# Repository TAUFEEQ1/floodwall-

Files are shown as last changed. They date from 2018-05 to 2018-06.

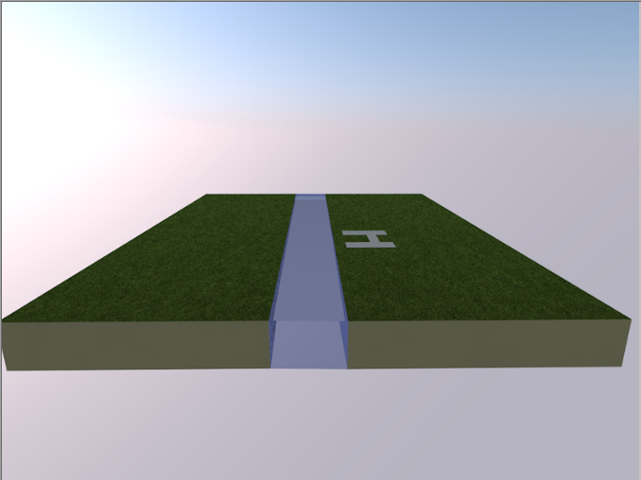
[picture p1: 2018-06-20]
barrier/barrier.PNG

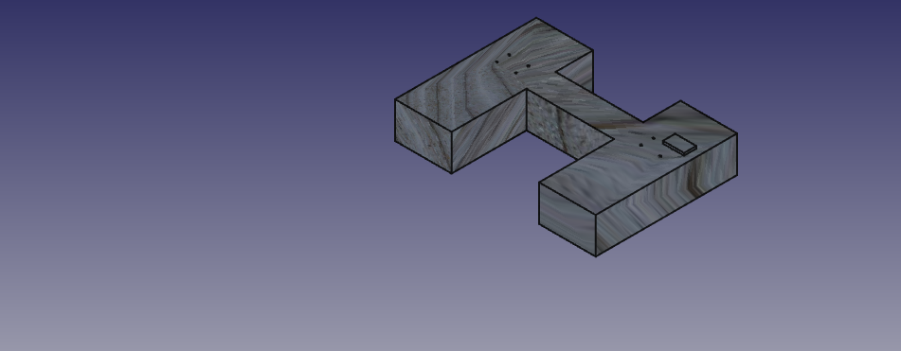
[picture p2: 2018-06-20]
barrier/c.png

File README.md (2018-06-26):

# floodwall-
Design of demountable flood barrier using julia and freecad.
# Operation
To ensure the proper functioning of the program, a bash / batch script exists in this project at barrier.sh or barrier.bat for windows.
Changing the parameters will change the dimensions of the barrier.
The main program written in julia is barrier1.jl. It depends of other julia scripts used in the design and estimation of the dimensions.
The main program accepts commandline arguments specified by the user from which it designs the flood barrier wall.
The julia program calculates the design dimensions which are then passed to a python script(FreeCAD).
The python script then outputs step files (in the simulations directory) that can be utilized by other CAD programs.
# Help
To see what command line options are available, run the main script with the help option specified,
  barrier1.jl --help
More documentation is to be provided soon.
# Dependecies.
Julia above v0.4 is needed.
CSV and Argparse libraries have to be installed via Pkg.add() in the julia console.
FreeCAD above version 0.16 is needed.

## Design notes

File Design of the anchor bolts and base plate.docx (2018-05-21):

# Design of the anchor bolts and base plate

The following section contains details on how the anchor bolt and base plate will be determined following the book,Guide on Design of post-installed anchor bolt systems in Hong Kong by Dr. S.S.H Cho and Ir Prof. SL Chan Department of Civil and Environmental Engineering, The Hong Kong Polytechnic University.

## Anchor bolts

Types of anchor bolts

To suit different needs and the conditions of the base materials, there are many types of anchor bolts as shown in Figure 2.1 such as:

a) Torque-controlled expansion anchor (sleeve type and wedge type)
b) Deformation-controlled expansion anchor
c) Undercut anchor
d) Concrete screw
e) Chemical anchor
f) Expansion chemical anchor

For the purposes of this project two types of bolts are candidates for usage which include the undercut anchor bolt and the concrete screw.

Undercut anchors develop mechanical interlock between anchor and base material. The undercutting can be achieved by a special drilling tool or by the anchor itself during installation. Then the expansion “sleeve” will fill the undercut hole and develop a tensile resistance.

Concrete screws are screwed into pre-drilled holes by a special screwdriver. The threads will cut into the concrete and create mechanical interlock between screw and concrete.

## Bolt configurations

When designing anchor bolt joints it is important to recognize that they are several recommended (ETAG 001, Annex C [1]) and widely used configurations.

Equally important is the special considerations to be made if the anchor bolt is too close to the edge. as this renders the joint susceptible to concrete edge failure. Therefore, in ETAG 001, Annex C [1], TR029 [5] and CEN/TS 1992-4 [2], bolt configurations for bolts close to edge will have a more stringent requirement.

The design proposed by the author ensures that the anchor bolts are far from the concrete edge and thus the above suggested measures may not be taken.

Configuration chosen is shown below:

## Minimum bolt spacing and edge distance requirements

Design engineers shall refer to manufacturer design manual for minimum bolt spacing requirement and minimum edge distance requirement which are normally determined by tests and mentioned in the relevant approval documents.

## Base Materials.

The concrete structures shall be of normal weight concrete with grades ranging from C25 to C60 (i.e. characteristic cube strength of concrete ranging from 25N/mm2 to 60N/mm2.

As a conservative approach, cracked concrete shall be assumed for anchor bolt design if the condition of concrete is not known.

## Static analysis of anchor bolts

### General

A fastening can be subject to tension, compression, shear forces, moments, torsion, or the combination of above.

These forces are resolved into shear and tension of individual bolts. Therefore, an anchor bolt can be subject to the following loading conditions:

a) Tension force only
b) Shear force only
c) Combined tension and shear

In general, elastic analysis may be used for calculating the loads on individual anchor bolts both at ultimate and serviceability limit states.

Tension force per anchor bolt According to the theory of elasticity a linear distribution of strains across the base plate and a linear relationship between strains and stresses exists (Figure 3.1). This assumption is valid only if the base plate is rigid and does not deform significantly. The base plate should remain elastic under design forces and its deformation should be compatible with the displacement of the anchor bolts.

For the determination of forces of the anchor bolts the following assumptions may be used:

1) The axial stiffness of all fasteners is equal. The anchor bolt threaded area shall follow the manufacturer specifications and the modulus of elasticity of steel shall follow the Code of Practice for the Structural Use of Steel [6] and is taken as 205 000 N/mm2.
2) The modulus of elasticity of the concrete depends on the concrete grade and shall follow the Code of Practice for Structural Use of Concrete [7].
3) Anchor bolts in the zone of the base plate under compression do not take forces. The compression force is taken by the base plate and transferred to base concrete.

The compressive stress in the concrete and the tension force in the anchor bolts can be solved by finding the neutral axis of the base plate under axial force and moments. The neutral axis can be found by solving a cubic equation by numbers of iteration. Therefore, it is best to use design software to obtain the tension force in the anchor bolts. However, under some simple loading conditions as in the following sections, the tension forces of individual anchor bolts can be solved by simple hand calculation.

### General

The failure modes of mechanical anchors under tension forces include:

a) Steel failure
b) Pull-out failure
c) Concrete cone failure
d) Splitting failure

The failure modes of mechanical anchor under shear forces include:

a) Steel failure
b) Concrete edge failure
c) Concrete pry-out failure

It is almost impossible to predict the failure mode of an anchor bolt or a bolt group which governs the resistance as it depends on a couple of factors such as the magnitude and direction of forces, anchor bolt grade, concrete condition and grade, embedment depth, edge distance, bolt spacing, etc. Therefore, it is necessary to calculate the resistance of each failure mode. In fact, manufacturers will provide all the values of design resistance under different failure modes of a single anchor bolt and design guidelines in a design manual. Design engineers only need to follow the design manual to calculate the ultimate design resistance of an anchor bolt group (Chan).

Steel failure

Steel failure is the most straightforward failure mode. It is observed by fracture in the shaft or the thread area as shown in Figure 4.1. The design tensile resistance of anchor bolt can be found in manufacturer design manual; otherwise the characteristic value of bolt resistance, to tension of an anchor bolt can be calculated directly by;

N_(R KS) =A_s * f_(uk)

Where;

As = threaded area of an anchor bolt and given in manufacturer specifications.

Fuk = the ultimate tensile stress of the bolt.

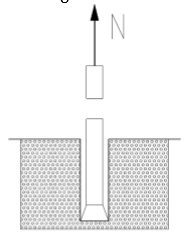
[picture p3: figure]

Figure 2-tensile failure in steel

Also recall that, the design resistance check requirements for mechanical anchor bolts in tension for this kind of failure are that:

N_(s d) ≤ N_(R d) =(N_(R KS))/(ɣ_(M S))

Where;

Nsd = design tension for a single anchor bolt.

ɣ_(M S) = factor of safety

Pull-out failure

Pull-out failure is a failure mode where the complete anchor bolt is pulled out of the hole as shown in Figure 4.2. The pull-out resistance, is determined by repetitive laboratory tests fulfilling the requirements in ETAG 001 [1] and engineers shall refer to manufacturer specifications for design values. However, in some cases, pull-out failure may not occur as the anchor bolts is failed by other failure mode such as concrete cone failure or steel failure. In this case, check against pull-out failure is not required.

Concrete cone failure

Concrete cone failure occurs when a cone-shaped break-out body is separated from the base concrete.

The characteristic cone resistance in ideal conditions can be got from the formula;

N_R^(°) _(kc) =k_c √(f_c)h_(ef)^1.5

Where;

k_c =factor specified by the manufacturer and dependent on the condition of the concrete

f_c = concrete characteristic cube strength in N/mm²

h_(ef) = embedment depth of the anchor in mm.

The values of commonly range from 7.0 to 7.2 for cracked concrete and 9.8 to 10.1 for non-cracked concrete. The actual value is given in the relevant approval documents (Chan).

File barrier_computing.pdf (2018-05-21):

2/18/2018 | barrier.jl
file:///tmp/tmpv_3068.html | 1/5 02/18/18 01:12:05 /home/nsamba/projects/barrier.jl 1 | #!/usr/bin/julia 23 | type | Barrier 4 | height 5 | base_width 6 | base_length 7 | base_thickness 8 | wall_thickness 9 | end 10 | barrier=Barrier(0,0,0,0,0) 11 | type | Constants 12 | spec_water 13 | spec_mat 14 | spec_base 15 | spec_soil 16 | mat_shear 17 | Cb 18 | Cf 19 | Kp 20 | Sb 21 | end 22 | constants=Constants(64,0,0,0,0,0,0,0,0) 23 | base_len(x)=0.40*x 24 | base_thick(x)=0.44*x 25 | Area(force,shear)=force/shear 26 | FArea(P,Sb)=P/Sb 27 | BArea(a,e)=a*e 28 | F_sta(pg,H)=4*0.5*pg*H^2 29 | weight(spec_wt,area,height)=spec_wt*area*height 30 | Fbuoy(spec_wt,area,height)=spec_wt*area*height 31 | Fv(wall,basew,Wwat,wallw,fb)=basew+wall+Wwat+wallw-fb 32 | Fr(Cf,fv)=Cf*fv 33 | Fc(Cb,B)=Cb*B 34 | Fp(kp,spec_soil,spec_water,t,len)=0.5*(kp*(spec_soil-spec_water)+spec_water)*(t^2)*len 35 | function | Fres(constants,barrier,Fst) 36 | wall_area=Area(Fst,constants.mat_shear) 37 | wall=weight(constants.spec_mat,wall_area,barrier.height) 38 | wc_area=(barrier.wall_thickness)^2 39 | wall_con=weight(constants.spec_soil,wc_area,barrier.height) 40 | base_area=BArea(barrier.base_width,barrier.base_length) 41 | basew=weight(constants.spec_base,base_area,barrier.base_thickness) 42 | pct=basew 43 | println("weight of base: | $pct") 44 | val=(2/3)*(barrier.base_width-barrier.wall_thickness) 45 | val1=(1/3)*barrier.base_width 46 | water_base=BArea(val,barrier.base_length)

file:///tmp/tmpv_3068.html | 2/5 47 | Wwat=weight(constants.spec_water,water_base,barrier.height) 48 | fb=Fbuoy(constants.spec_water,base_area,barrier.base_thickness) 49 | println("Bouyant Force: | $fb") 50 | fv=Fv(basew,wall,Wwat,wall_con,fb) 51 | println("Vertical force : | $fv") 52 | friction=Fr(constants.Cf,fv) 53 | fc=Fc(constants.Cb,barrier.base_width) 54 | fp=Fp(constants.Kp,constants.spec_soil,constants.spec_water,barrier.base_thickness,barrier.base_length) 55 | println("passive soil pressure: | $fp") 56 | resf=friction+fc+fp 57 | return | [resf,fv] 58 | end 59 | function | design(barrier,constants) 60 | #for redesign of barrier 61 | base_width=barrier.base_width 62 | println("Assuming base_length = 0.80 of base_width") 63 | barrier.base_length=base_len(barrier.base_width) 64 | println("Assuming base_thickness= 0.70 of base_width") 65 | barrier.base_thickness=base_thick(barrier.base_width) 66 | temp1=constants.spec_water 67 | temp2=barrier.height 68 | Fst=F_sta(temp1,temp2) 69 | println("hydrostatic force: | $Fst") 70 | println("Calculating opposing forces") 71 | Fresist=Fres(constants,barrier,Fst) 72 | ans=Fresist[1]/Fst 73 | tempv=Fresist[1] 74 | println("Resisting force: | $tempv") 75 | println(Fresist[1]) 76 | return | [ans,Fresist[2]] 77 | end 78 | function | ch_base(barrier,coef) 79 | height=barrier.height 80 | coef=coef+0.05 81 | barrier.base_width=coef*height 82 | return | coef 83 | end 84 | heel(x,z)=(2/3)*(x-z) 85 | toe(x,z)=(1/3)*(x-z) 86 | M_sta(fst,H,t)= | fst*((H+t)/3) 87 | M_fp(fpee,t)= | fpee*(t/3) 88 | M_bouy(fb1,fb2,B) | = | (fb1*(B/3)) | + | (fb2*(2/3)*B) 89 | Mbse(bw,B)=bw*(B/2) 90 | Mwallwt(Fwt,C,twall)= | Fwt*(C+(twall/2)) 91 | Mwh(waterw,B,Ah)=waterw*(B-(Ah/2)) 92 | fboy(a,H,twall,ah,t,len)= | a*((H)*(0.5*twall)+(ah*(twall/2)*(t)))*len 93 | function | Mres(barrier,constants) 94

file:///tmp/tmpv_3068.html | 3/5

fp=Fp(constants.Kp,constants.spec_soil,constants.spec_water,barrier.base_thickness,barrier.base_length)
95 | | base_area=BArea(barrier.base_width,barrier.base_length)
96 | | basew | | = | | weight(constants.spec_base,base_area,barrier.base_thickness)
97 | | Mbase | | = | | Mbse(basew,barrier.base_width)
98 | | fst=F_sta(constants.spec_water,barrier.height)
99 | | wall_area=Area(fst,constants.mat_shear)
100 | | wall=weight(constants.spec_mat,wall_area,barrier.height)
101 | | wc_area=(barrier.wall_thickness)^2
102 | | wall_con= | | | weight(constants.spec_soil,wc_area,barrier.height)
103 | | wallwt | | = | | wall_con+wall
104 | | Mwwt | | = | | Mwallwt(wallwt,toe(barrier.base_width,barrier.wall_thickness),barrier.wall_thickness)
105 | | water_area | | = | | BArea(heel(barrier.base_width,barrier.wall_thickness),barrier.base_length)
106 | | wh | | = | | weight(constants.spec_water,water_area,barrier.height)
107 | | Mwheel=Mwh(wh,barrier.base_width,heel(barrier.base_width,barrier.wall_thickness))
108 | | Mfp | | = | | M_fp(fp,barrier.base_thickness)
109 | | Mresisting=Mfp+Mwwt+Mbase+wh
110 | | println("And the resisting Moment is: | | | $Mresisting")
111 | | return | | Mresisting
112 | end
113 | function | | overturning(barrier,constants)
114 | | #barrier.base_thickness = base_thick(barrier.base_width)
115 | | #barrier.base_length = base_len(barrier.base_width)
116 | | fst=F_sta(constants.spec_water,barrier.height)
117 | | Mst=M_sta(fst,barrier.height,barrier.base_thickness)
118 | | hel=heel(barrier.base_width,barrier.wall_thickness)
119 | | toy=toe(barrier.base_width,barrier.wall_thickness)
120
fbuoy1=fboy(constants.spec_water,barrier.height,barrier.wall_thickness,hel,barrier.base_thickness,barrier .base_length)
121
fbuoy2=fboy(constants.spec_water,barrier.height,barrier.wall_thickness,toy,barrier.base_thickness,barrier .base_length)
122 | | Mbouy=M_bouy(fbuoy1,fbuoy2,barrier.base_width)
123 | | Mov=Mst+Mbouy
124 | | println("And the overturning Moment is: | | | $Mov")
125 | | Mresist=Mres(barrier,constants)
126 | | ans=Mresist/Mov
127 | | qns=[ans,Mres,Mov]
128 | | return | | qns
129 | end
130 | function | | main(barrier,constants)
131 | | println("Design Flood Elevation in ft")
132 | | height=readline(STDIN)
133 | | barrier.height=parse(Int8,height)
134 | | println("Assuming base_width = wall_height")
135 | | barrier.base_width=0.5*barrier.height
136 | | println("Wall thickness in ft")
137 | | wall_t=readline(STDIN)
138 | | barrier.wall_thickness=parse(Float32,wall_t)

file:///tmp/tmpv_3068.html | 4/5 139 | println("Establishing constants....") 140 | println("Insert soil specific weight in Ib/ft3 ") 141 | spec_soil=readline(STDIN) 142 | constants.spec_soil=parse(Int16,spec_soil) 143 | println("Insert material specific weight in Ib/ft3") 144 | spec_mat=readline(STDIN) 145 | constants.spec_mat=parse(Int16,spec_mat) 146 | println("Insert material shear strength in Ib/ft2 ") 147 | mat_shear=readline(STDIN) 148 | constants.mat_shear=parse(Float32,mat_shear) 149 | constants.mat_shear=(10^6)*constants.mat_shear 150 | println("Insert cohesion coefficient") 151 | cohe=readline(STDIN) 152 | constants.Cb=parse(Float32,cohe) 153 | println("Insert friction coeffiecient") 154 | frct=readline(STDIN) 155 | constants.Cf=parse(Float32,frct) 156 | println("Insert passive pressure coeffiecient") 157 | kp=readline(STDIN) 158 | constants.Kp=parse(Float32,kp) 159 | println("Insert base specific weight") 160 | spec_base=readline(STDIN) 161 | constants.spec_base=parse(Int16,spec_base) 162 | println("Allowable bearing Capacity of soil") 163 | Sb=readline(STDIN) 164 | constants.Sb=parse(Int16,Sb) 165 | println("Design Against Failure by sliding | ") 166 | answer=design(barrier,constants) 167 | i | = | answer[1] 168 | coef= | 0.5 169 | y= | answer[2] 170 | while | i | < | 1.5 171 | println("Changing base_width") 172 | coef= | ch_base(barrier,coef) 173 | answer=design(barrier,constants) 174 | i= | answer[1] 175 | end 176 | output_dimensions(barrier) 177 | println("designing against overturning moments | ") 178 | answer | = | overturning(barrier,constants) 179 | ncoef=coef 180 | j | = | answer[1] 181 | while | j | < | 1.5 182 | ncoef | = | ch_base(barrier,ncoef) 183 | answer | = | overturning(barrier,constants) 184 | j | = | answer[1] 185 | end 186 | println("Adjusted dimension for overturning moments | ") 187 | output_dimensions(barrier)

file:///tmp/tmpv_3068.html | 5/5
188 | end
189 | function | | output_dimensions(barrier)
190 | | height=barrier.height
191 | | bwd=barrier.base_width
192 | | blen=barrier.base_length
193 | | bthick=barrier.base_thickness
194 | | println("base_width: | | | $bwd")
195 | | println("base_length: | | | $blen")
196 | | println("base_thickness: | | | $bthick")
197 | | print("Wall props..")
198 | | wallt | | = | | barrier.wall_thickness
199 | | wallh | | = | | barrier.height
200 | | println("Wall height: | | | $wallh")
201 | | println("Wall thickness: | | | $wallt")
202 | end
203 | main(barrier,constants)
204

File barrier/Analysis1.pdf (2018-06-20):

## Analysis1

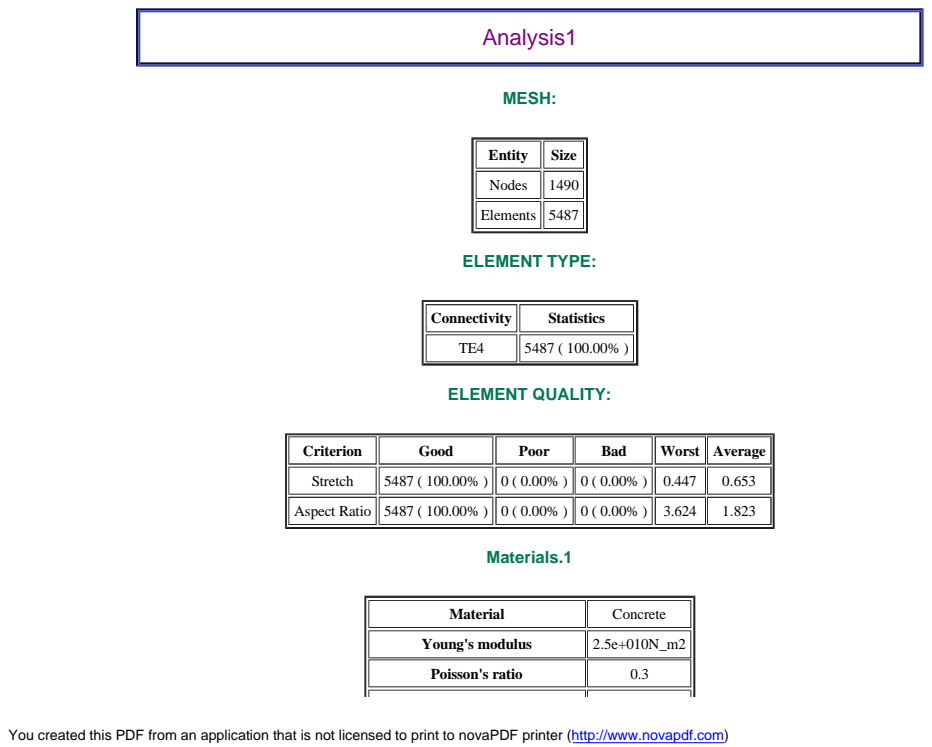
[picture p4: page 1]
MESH:; Entity; Size; Nodes; Elements 5487; ELEMENT TYPE:; Connectivity; Statistics; ELEMENT QUALITY:; Criterion; Good; Poor; Bad; Worst Average; Stretch; Aspect Ratio 5487 ( 100.00% ) 0 ( 0.00% ) 0 ( 0.00% ) 3.624; Materials.1; Material; Concrete; Young's modulus; Poisson's ratio

You created this PDF from an application that is not licensed to print to novaPDF printer (http://www.novapdf.com)

Density | 2320kg_m3
Coefficient of thermal expansion | 1e-005_Kdeg
Yield strength | 0N_m2

## Static Case

Boundary Conditions

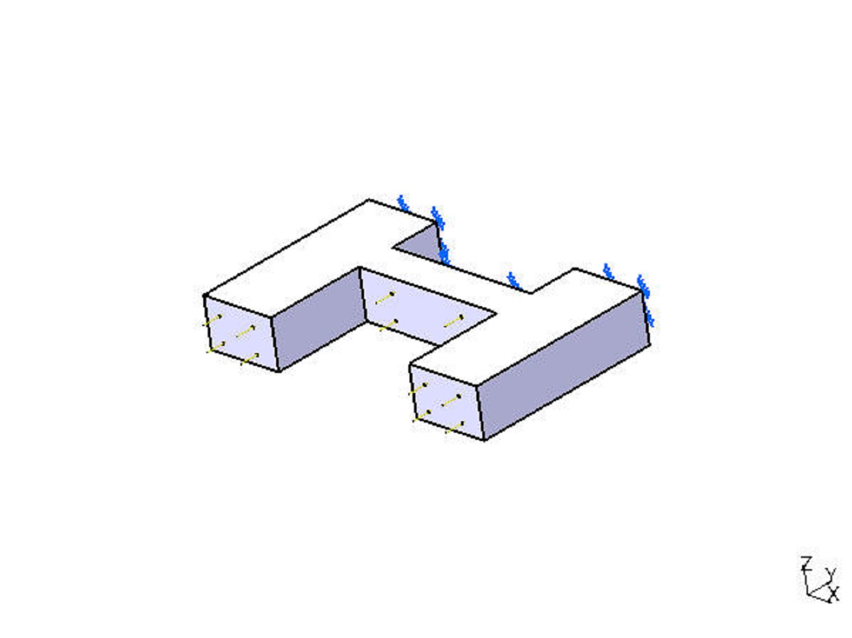
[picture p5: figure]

Figure 1

STRUCTURE Computation

Number of nodes | : | 1490
Number of elements | : | 5487

Number of D.O.F. | : | 4470
Number of Contact relations | : | 0
Number of Kinematic relations | : | 0
Linear tetrahedron | : | 5487

RESTRAINT Computation

Name: RestraintSet.1

Number of S.P.C : 405

LOAD Computation

Name: Loads.1

Applied load resultant :

Fx | = | 2 | . | 608e-008 | N
Fy | = | 2 | . | 136e+004 | N
Fz | = | 0 | . | 000e+000 | N
Mx | = | -4 | . | 098e+003 | Nxm
My | = | -1 | . | 254e-007 | Nxm
Mz | = | 1 | . | 062e-005 | Nxm

STIFFNESS Computation

Number of lines | : | 4470
Number of coefficients | : | 79968
Number of blocks | : | 1
Maximum number of coefficients per bloc | : | 79968
Total matrix size | : | 0 | . | 93 | Mb

SINGULARITY Computation

Restraint: RestraintSet.1

Number of local singularities | : | 0
Number of singularities in translation | : | 0
Number of singularities in rotation | : | 0
Generated constraint type | : | MPC

CONSTRAINT Computation

Restraint: RestraintSet.1

Number of constraints | : | 405
Number of coefficients | : | 0
Number of factorized constraints | : | 405
Number of coefficients | : | 0
Number of deferred constraints | : | 0

FACTORIZED Computation

Method | : | SPARSE
Number of factorized degrees | : | 4065
Number of supernodes | : | 681
Number of overhead indices | : | 26238
Number of coefficients | : | 284937
Maximum front width | : | 210
Maximum front size | : | 22155
Size of the factorized matrix (Mb) | : | 2 | . | 1739
Number of blocks | : | 1
Number of Mflops for factorization | : | 3 | . | 184e+001
Number of Mflops for solve | : | 1 | . | 160e+000
Minimum relative pivot | : | 8 | . | 073e-002

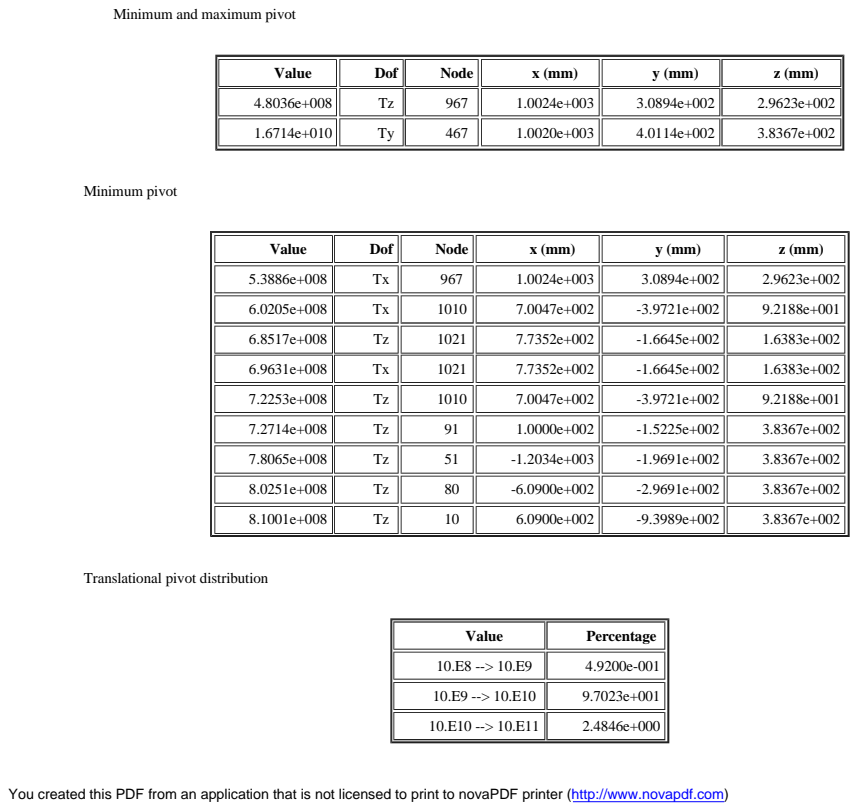
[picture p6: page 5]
Value; Dof; Node; Minimum pivot; Percentage

Minimum and maximum pivot

Translational pivot distribution

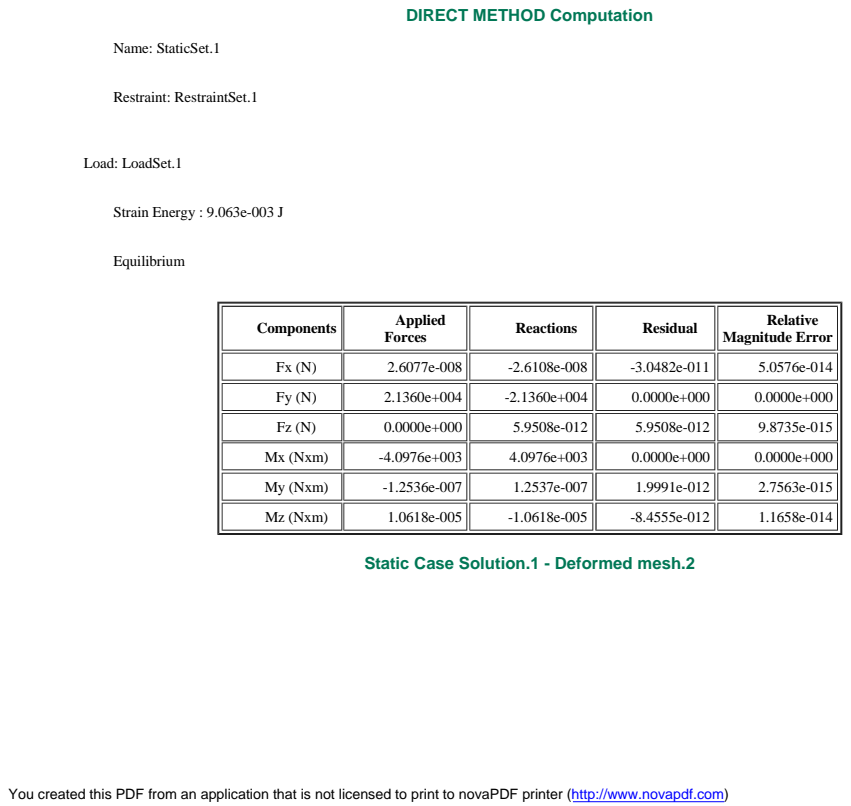
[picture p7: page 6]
Name: StaticSet.1; Restraint: RestraintSet.1; Load: LoadSet.1; Strain Energy : 9.063e-003 J; Equilibrium; Components; Applied; Forces; Reactions; Residual; Relative; Magnitude Error; Mx (Nxm); My (Nxm); Mz (Nxm)

DIRECT METHOD Computation

Static Case Solution.1 - Deformed mesh.2

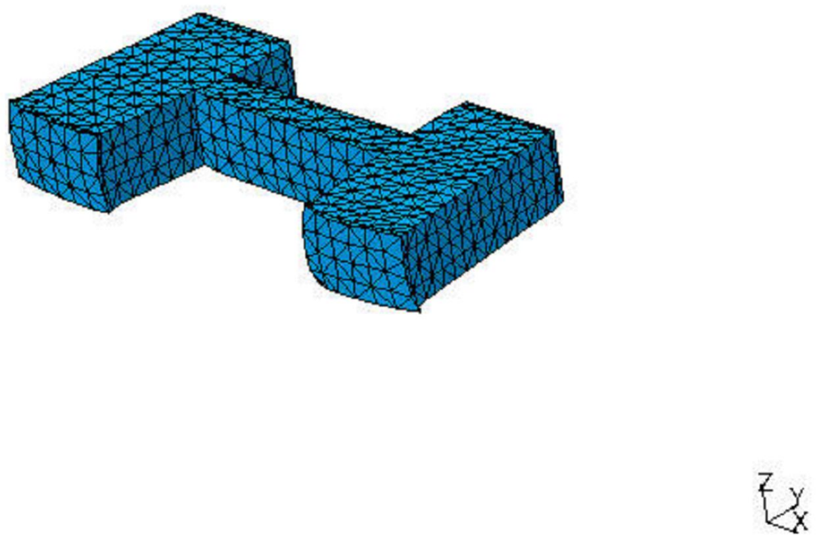
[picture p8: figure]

Figure 2

On deformed mesh ---- On boundary ---- Over all the model

Static Case Solution.1 - Von Mises stress (nodal values).2

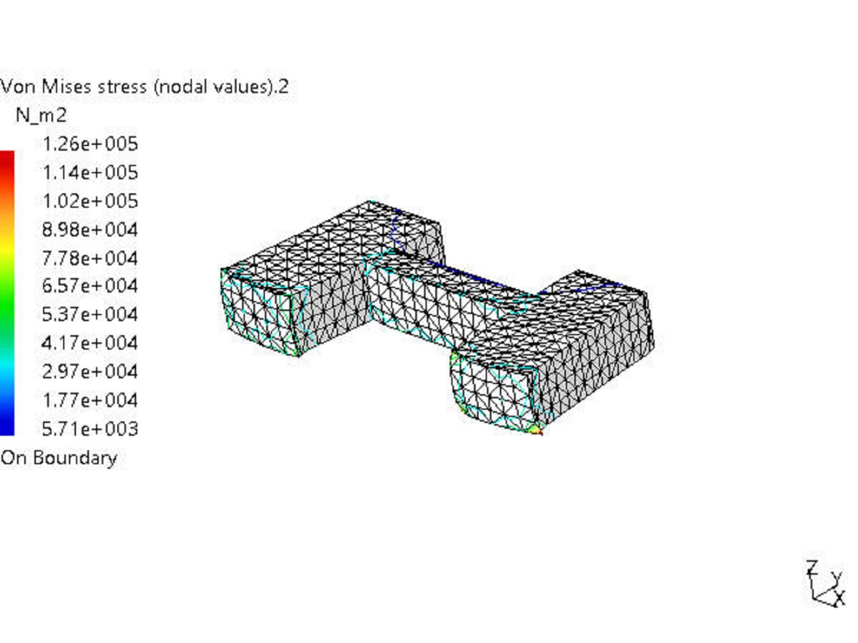
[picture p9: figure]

Figure 3

3D elements: : Components: : All

On deformed mesh ---- On boundary ---- Over all the model

Static Case Solution.1 - Deformed mesh.1

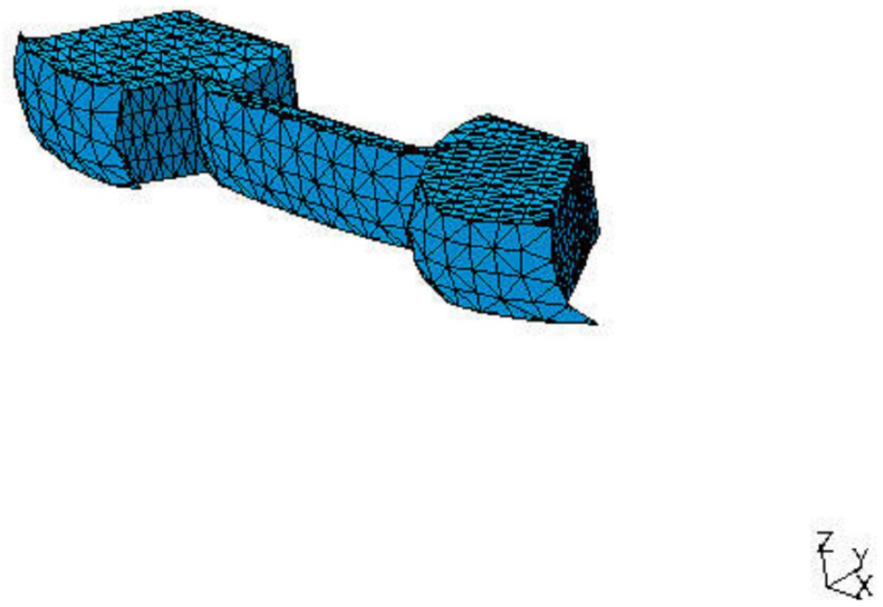
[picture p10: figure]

Figure 4

On deformed mesh ---- On boundary ---- Over all the model

Static Case Solution.1 - Translational displacement vector.1

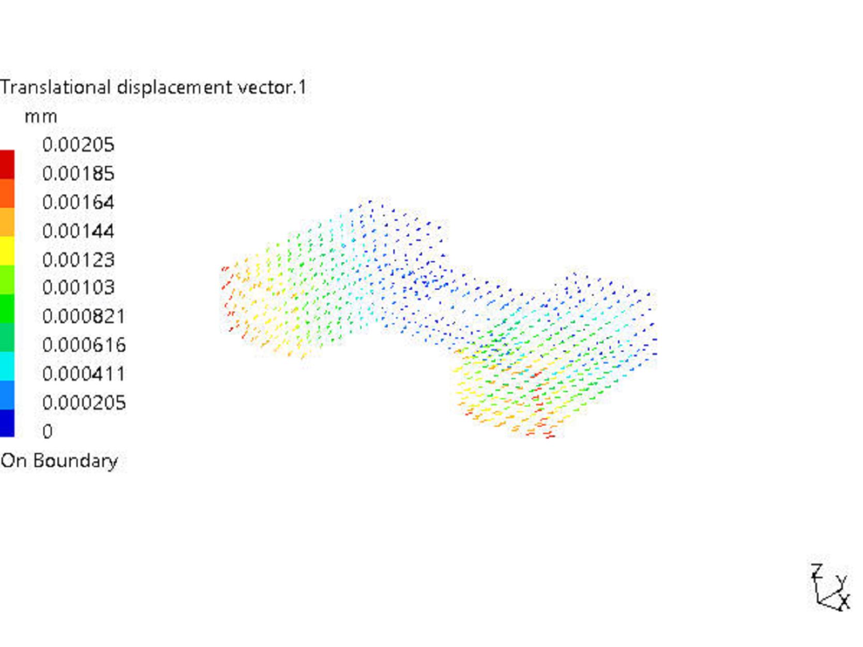
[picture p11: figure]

Figure 5

3D elements: : Components: : All

On deformed mesh ---- On boundary ---- Over all the model

Global Sensors

Sensor Name Sensor Value

Energy | 0.009J

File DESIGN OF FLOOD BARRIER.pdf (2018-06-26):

i

MAKERERE | UNIVERSITY

## COLLEGE OF ENGINEERING ART DESIGN

## AND TECHNOLOGY

## DEPARTMENT OF MECHANICAL ENGINEERING

## DESIGN OF DEMOUNTABLE FLOOD BARRIER

Name: Nsamba Taufeeq

Student No.:214000192

Registration No: 14/U/983

Sign: |
Date: |
Lead Supervisor: | Co-Supervisor:
Name: Dr Norbert Mukasa | Name: Dr Hillary Kasedde
Sign: | | Sign: |
Date: | | Date: |

ii

Declaration
I NSAMBA TAUFEEQ declare that this report is a result of my own work. It is the

summation of research and ultimate design of a demountable flood barrier. The activities, the

methods and the computer code are hereby free to be used for academic and commercial

purpose by whosoever chooses.

The Author:

Name: Nsamba Taufeeq | Sign: |
Date: |

iii

ACKNOWLEDGEMENT
The success of this project is attributed to the extensive support and great assistance from my

main project supervisor Dr. Norbert Mukasa and my co-supervisor Dr. Hillary Kasedde for

their helpful guidance, suggestions and encouragement throughout this project. I am also

grateful to Engineer Moses Matovu for his valuable and helpful guidance. This study could

not have been successfully done without his useful comments.

Special thanks go to the members of the FreeCAD forum, especially Mr Yorik for his help

with the FreeCAD python scriptingmodules.

I would like to thank members of Julia community for creating and maintaining in my

opinion the most revolutionary technical computing programming language to date.

I would also like to thank my teachers, friends and the staff of the Mechanical and Civil

EngineeringDepartments of Makerere University for all their support. Finally, I am

extremely grateful to my family for all the support provided.

iv

Contents

v

vi

vii

### List of figures

viii

List of tables:

ix

### ABSTRACT

In recent decades due to global climate change, hundred year floods have been occurring worldwide with frightening regularity. Flooding is a natural phenomenon of the environment however floods are known to be the most common natural disaster. Extreme global flooding with increased frequency affects both the developed and the developing world with catastrophic results . (A. Mugesh, 2015).

The case study was lubigi catchment in Kampala city. The catchment suffers from flooding events occurring every year and affecting a large number of the population, mainly poor and threatening their livelihood. Flood evidences are numerous in Lubigi flood plains. Different coping strategies can be seen in every corner of habited flood plain where different structural measures were adopted by the community (Habonimana, 2014).

There have also been various attempts (Dr. Richard Sliuzus, 2013) by the government to mitigate flooding at these sites in spite of which there still exists flooding in lubigi floodplains. Consequently, Lubigi floodplains were used as the case study of this project.

A demountable movable community flood barrier system consisting of an assembly of components/pieces that are detachable to allow transportation and quick installation in flood prone area during flood season was therefore designed as a means to mitigate this flooding problem. The nature of this system is such that it allows limited access to the channel when deployed and may require disassembly to resume full access to the channel.

The structure design procedures were used to build a computer program in Julia to implement those procedures as many were iterative. The program’s results were then used by a separate computer program built in python which built CAD models that were then tested with Finite Element Analysis software in CATIA.

Using a flood height of 0.909m (3ft) that is above the flood levels range 0.6m-0.8m from (Dr. Richard Sliuzus, 2013; Habonimana, 2014),the structure was designed and subsequently tested for structural integrity or strength with CATIA Finite Element Analysis tools. The flood barrier was found to retain its structural integrity.

Keywords:

Flood protection, temporary flood protection, demountable flood protection, flood barrier,
failure | ,operation, | flood | defences.

CHAPTER ONE: INTRODUCTION

### 1.1 BACKGROUND

Flooding may occur as an overflow of water from water bodies, such as a river, lake or ocean, in which the water overflows, resulting in some of that water escaping its usual boundaries, or it may occur due to an accumulation of rainwater on saturated ground in a real flood.

In recent decades due to global climate change, hundred year floods have been occurring worldwide with frightening regularity. Flooding is a natural phenomenon of the environment however floods are known to be the most common natural disaster. Extreme global flooding with increased frequency affects both the developed and the developing world with catastrophic results . (A. Mugesh, 2015).

As the population of this country grows, the pressure on resources such as land may lead to further wetland reclamation and increase in magnitude of flooding as several studies (Xianghu Li, 2014) have shown, the case for flood protection cannot be more urgent.

The focus of this project is on river / water channel overflow related flooding and although the extent to which this type of flooding affects this country is unclear. There exists a slew of newspaper articles reporting destruction of homes, lives and property. As of such, this project aims to seek for an engineering solution to protect the lives and homes of people at risk of river overflow flooding.

There have been various occurrences of floods resulting from rivers bursting their banks. Three particular cases stand out as they are somewhat documented better than the rest.

In one case river Nyamambwa located in Kasese, western region of the country flooded in the year 2014.The damage from this flood according to a New Vision article resulted in 1000 displaced people.

In another case on Tuesday 12 April 2016, Heavy rainfall caused river Mubuka to overflow displacing more than 1000 people in the parishes of Kanamba and Karusandara sub-county.(According to a report by Bernard Juma on floodlist.com).

In the third case a report from Daily Monitor published on 2nd October 2007 by Fred Muzaale and others says heavy rainfall during that time caused river Sezzibwa to burst its banks destroying 60 homes built close to its banks.

The traditional approach to flood protection taken by the public as well as many flood protection professionals as in the realm of civil engineering is of permanent engineered structures such as flood walls, flood embankments and large gated barriers.Although these methods have seen adoption by the developed world, this however has not been the case for developing countries particularly in as it relates to Uganda.

There are varying reasons for which this has been the case but one of the major reasons is these projects are of such high costs and yet owing to their permanent nature have very low flexibility.This results in a need for flood protection solution that is affordable and flexible specifically in as it relates to Uganda.

It is in this line of thought that the author proposes a temporary and demountable flood protections system which simply stated is a moveable flood protection system that is fully pre-installed and requires operation during flood event or one that requires part installation into pre-installed guides or sockets with a pre-constructed foundation.

The words temporary flood protection imply that the system is a removable flood protection system, wholly installed during flood event and completely removed when levels have receded.

It should however be noted that temporary and demountable flood protection systems result in risk of operational failure. To remove this risk a decision should always be made to use a permanent system if it is technically and economically viable as well as environmentally and locally acceptable.

### 1.2 Problem Statement:

Traditional flood defences that are of the temporary or movable type have mostly seen adoption to protect residential areas and individual homes. This leaves the complementary type(permanent flood defences) as the only solution that has seen common adoption by countries such as the United States(The Great Wall of Louisiana),United Kingdom(The Thames barrier),Netherlands(Eastern Sheldt Storm Surge Barrier).The challenge with these technologies is in their design as permanent structures that is they cannot be moved or transported to other sites.

As floods in this country, Uganda are seasonal and that Uganda is a developing country with limited financial resources, this project aims to design a demountable flood barrier system that can be detached or disassembled when not in use to resume full access to the river and can be moved to other locations.

1.3 SCOPE OF THIS PROJECT.
The project proposed herein will not cover policy and meteorological aspects pertaining to river / channel overflow flooding in this country. However this project only aims to devise a community temporary/demountable flood barrier system that will ultimately protect communities leaving in or around river flood plains in Uganda.

1.4 JUSTIFICATION.
This project recognises that there is a flooding problem in this country and that the existing community protection defences globally are such expensive solutions that is permanent flood control structures are such expensive projects to set up and maintain though reliable.

In recognition of the seasonal nature of flooding, the project aims to propose a design of a demountable system to lower cost of maintaining. The portability of the demountable flood barrier system will ensure that fewer units of this structure will be manufactured as they will be deployable to other water channels.

### 1.5 CASE STUDY

The study case was lubigi catchment in Kampala city.The catchment suffers from flooding events occurring every year and affecting a large number of the population, mainly poor and threatening their livelihood. Flood evidences are numerous in Lubigi flood plains.Different coping strategies can be seen in every corner of habited flood plain where different structural measures were adopted by the community.

There have also beenvarious attempts by the government to mitigate flooding at these sites despite of which there still exists flooding in lubigi floodplains. Following this,the author proposes to use Lubigi floodplains as the case study of this project.

### 1.6 OBJECTIVES

1.6.1 Main objective:The main objective of this project is to design and model a temporary and demountable flood barrier system using computer software to protect communities in Uganda from river overflow flooding.

### 1.6.2 Specific Objectives:

- To study existing flood protection technologies.
- To identify flood prone areas along the channel.
- To design the flood barrier.
- To simulate the system.

CHAPTER TWO: LITERATURE REVIEW

2.1 |Introduction
There are a variety of technologies that have been invented and used to control and prevent flooding.Some of which have been devised to protect entire comunities from flooding,others done to protect individual homes and residential areas.The following is a review of existing technologies,their strengths,their weaknesses and what this technology this project proposes to improve.

NOTE:
Although some or many of the technologies discussed in this section are used to protect coastal societies,the author sees it relevant as they could still be applied to river overflow scenarios.

First we begin this with the technologies used to protect communities.

2.2 The Thames Barrier.

The Thames Barrier is a unique flood control structure on the River Thames at Woolwich Reach in East London.It is 520 metres wide and protects London against storm surges and rainfall swelling.

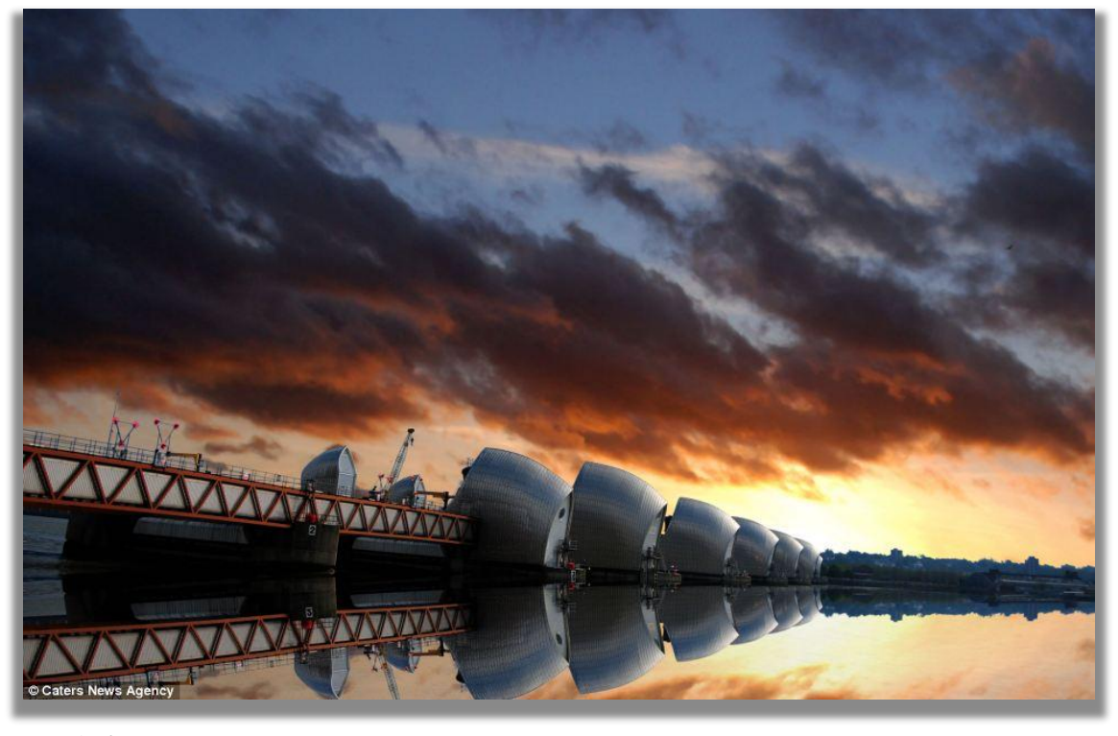
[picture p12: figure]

Figure 1-Thames Barrier

Photo- 1-Courtesy of Cater News Agency

The barrier currently protects 125sq Km of London including an estimated 1.25 million people,250,000 GBP worth of property and infratructure,a large propotion of the London tube network and many historic bulding,power supplies,hospitals and schools.It took 8 years to build the structure,costing 535million GBP of that tme and became fully operational in 1982.

### 2.2.1 Operation

The barrier is a series of 10 separate movable steel gates,standing 20 metres tall and strecthing 520 metres across the river.

Each of the main gates is a hollow steel-platted structure over 20m high and weighng 3700 tonnes capable of withstanding an overall load of more than 9000 tonnes of water.

When the barrier is closed, a solid steel wall sealing the upper part of the rver from the sea is created , stopping water from flowing upstream towards the capital.The gates can also be part closed in the underspill position,allowing a controlled amount of water to pass under the gate and up the river.
Individual gates can be closed in ten minutes but the whole barrier takes around one hour and a half to close completely.
The barrier is only reopened once the water level upstream of the barrier matches water level downstream.When not in use,the gates rest out of sight in curved recessed concrete cils in the riverbed which allows river traffic to pass through.

2.3 The Eastern Scheldt Barrier.

Figure 2-Eastern Sheldt Barrier.

2.3.1 Operation
The dam is manually operated but if human control fails, an electronic security system acts as a backup. A Dutch law regulates the conditions under which the dam is allowed to close. The water levels must be at least three meters above regular sea level before the doors can be completely shut. Each sluice gate is closed once a month for testing. Emergency procedures are tested on pre-scheduled dates. Once the test is passed, the shutters are quickly opened again to create a minimum amount of effect on tidal movements

And the local marine ecosystem. It takes approximately one hour to close a door. The cost of operation is €17 million per year.

The full dam has been closed twenty-five times since 1986, due to water levels exceeding or being predicted to exceed the three meters. The last time was on 21 October 2014.

### 2.4 The Maeslantkering

The Maeslantkering is a storm surge barrier on the NieuweWaterweg, Netherlandswhich is controlled by a supercomputer and closes if the city of Rotterdam is threatened by floods.

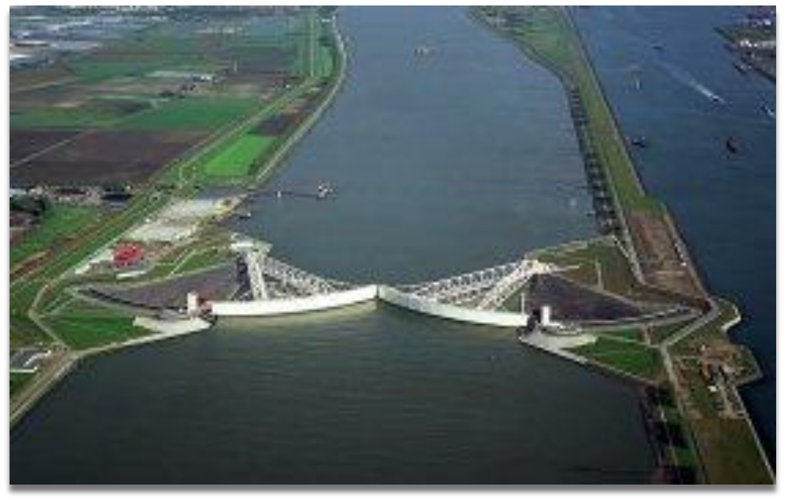
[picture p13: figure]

Figure 3-Maeslantkering

2.4.1 Operation
The barrier is connected to a computer system which is linked to weather and sea level data. Under normal weather conditions the two doors themselves are well protected in their dry docks and a 360-metre wide gap in the waterway gives ships enough space to pass without any inconvenience. But when a storm surge of 3 metres above normal sea level is anticipated in Rotterdam, the barrier will be closed automatically. Four hours before the actual closing procedure begins, incoming and outgoing ships are warned. Two hours before closing the traffic at the NieuweWaterweg comes to a standstill. Thirty minutes before closing the dry docks that contain the gates are flooded. After this, the gates start to float and two so-called "loco mobiles" move the gates towards each other. When the gap between the gates is about 1.5 metre-wide, water is let inside the hollows of the gates, so that they submerge to the bottom of the waterway. The bottom has been elaborately dug and then laid with layers of broken stone, so that the gates are able to form a relatively watertight fit when submerged. In cases where the gates have to be shut for a prolonged period, which would cause the waters of the Rhine to rise behind them, the gate hollows are partly emptied and floated, so that excess river water runs out to sea, before they are submerged again. The decision-making algorithm that sequences storm surge-triggered events in the Maeslantkering is run entirely by computer.

2.5 Passive flood barriers.
Passive barriers will operate automatically in a flood or storm event, requiring no humanintervention or electricity. In its guidance for floodproofing non-residential buildings, FEMA recommends passive intervention whenever possible1. A passive barrier can be permanently fixed, such as a floodwall or levee, or a barrier that activates during a flood. Barriers that self-activate are generally used in tandem with permanent floodwalls or other barriers, and deploy to protect entryways or other openings behind the barrier. Typically, self-activating barriers use water pressure or action to deploy. (ABC- A Better City, 2015)

2.6 Flood walls and leeves.
A properly designed and constructed floodwall or levee can often be an effective device for repelling floodwaters. Both floodwalls and levees provide barriers against inundation, protect buildings from un-equalized hydrostatic and hydrodynamic loading situations, and in some cases may deflect floodborne debris away from buildings. However, floodwalls and levees differ in their design, construction, site characteristics, and application.

Floodwalls are structures constructed of manmade materials such as concrete or masonry. The selection of a floodwall design is primarily dependent on the type of flooding expected at the building’s site. High water levels and velocities can exert hydrodynamic and hydrostatic forces and impact loads, which must be accounted for in the floodwall design. The composition of any type of floodwall must address three broad concerns:

- Overall stability of the wall as related to the external loads;
- Sufficient strength as related to the calculated internal stresses; and
- Ability to provide effective enclosures to repel floodwaters.

These internal and external forces pose a significant safety hazard if floodwalls are not properly designed and constructed, or their design level of protection is overtopped. Additionally, a tall floodwall can become very expensive to construct and maintain, and can require additional land area for grading and drainage. Therefore, in most instances, residential floodwalls are practical only up to a height of 3 to 4 feet above.

### 2.6.0 Floodwalls

A floodwall is a free standing,permanent engineered structured structure designed to prevent encroachment of floodwaters.Floodwalls are typically constructed of reinforced concrete or masonry,provide a barrier against inundation, protect structures from hydrostatic and hydrodynamic loads, and may deflect flood borne debris away from the structure.

Types of Floodwalls

There are two basic types of flood wall:

Those that also form part of the river frontage,such as wharf, retaining wall,or quay.

Those that are remote from the river, generally with the sole purpose of providing a flood defence.

### 2.6.1 Gravity Floodwall

A gravity wall consists of mass concrete generally without reinforcement. It is proportioned so that the resultant of the forces acting on any internal plane through the wall falls within, or close to the kern of the section.A small tensile stress capacity is permissible for localised stresses due to extreme and temporary loading conditions. (Engineers, 1989)

As its name implies, a gravity floodwall depends upon its weight for stability. The gravity wall’s structural stability is attained by effective positioning of the mass of the wall, rather than the weight of the retained materials. The gravity wall resists overturning primarily by the dead weight of the concrete and masonry construction. It is simply too heavy to be overturned by the lateral flood load. (fema.gov; Agency, 2012)

Frictional forces between the concrete base and the soil foundation generally resist sliding of the gravity wall. Soil foundation stability is achieved by ensuring that the structure neither moves nor fails along possible failure surfaces. Gravity walls are appropriate for low walls or lightly loaded walls. They are relatively easy to design and construct. The primary disadvantage of a gravity floodwall is that a large volume of material is required. As the required height of a gravity floodwall increases, it becomes more cost-effective to use a cantilever wall. (fema.gov; Agency, 2012)

Figure 4-Gravity Floodwall

### 2.6.2 Cantilever Floodwall

A cantilever wall is a reinforced-concrete wall (cast-in-place or built with concrete block) that utilizes cantilever action to retain the mass behind the wall. Reinforcement of the wall is attained by steel bars embedded within the concrete or block core of the wall . Stability of this type of wall is partially achieved from the weight of the soil on the heel portion of the base, as illustrated in Figure-2.

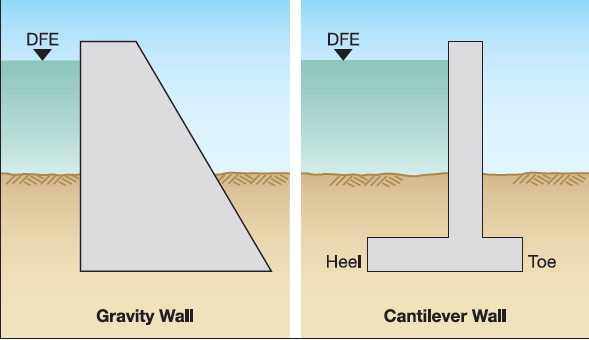
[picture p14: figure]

Figure 5-Gravity and Cantilever floodwall

The floodwall is designed as a cantilever retaining wall, which takes into account buoyancy effects and reduced soil bearing capacity. However, other elements of a floodproofing project (i.e., bracing effects of any slab-on-grade, the crosswalks, and possible concrete stairs) may help in its stability. This results in a slightly conservative design for the floodwall, but provides a comfortable safety factor when considering the unpredictability of the flood. Backfill can be placed along the outside face of the wall to keep water away from the wall during flooding conditions. (fema.gov)

NOTE:Reinforced concrete provides an excellent barrier in resisting water seepage, since it is monolithic in nature. The reinforcement not only gives the wall its strength, but limits cracking as well.

The concrete floodwall may be aesthetically altered with a double-faced brick application on either side of the monolithic cast-in-place reinforced concrete centre. This reinforced concrete core is the principal structural element of the wall that resists the lateral hydrostatic pressures and transfers the overturning moment to the footing. The brick-faced wall is typically used on homes with brick facades. Thus, the floodwall becomes an attractive modification to the home. In terms of the structure, the brick is considered in the overall weight and stability of the wall and in the computation of the soil pressure at the base of the footing, but is not considered to add flexural strength to the floodwall.

When the flood protection elevation requirements of a gravity or cantilever wall become excessive in terms of material and cost, alternative types of floodwalls can be examined. The use of these floodwall alternatives is generally determined by the relative costs of construction and materials, and amount of reinforcement required.

### 2.6.3 Buttressed Floodwall

A buttressed wall is very similar to a counterfort wall. The only difference between the two is that the transverse support walls are located on the side of the stem, opposite the retained materials. (fema.gov)

### 2.6.4 Counterfort Floodwall

A counterfort wall is similar to a cantilever retaining wall except that it can be used where the cantilever is long or when very high pressures are exerted behind the wall. Counterforts,or intermediate traverse support bracing, are designed and built at intervals along the wall and reduce the design forces. (fema.gov)

2.6.6 Braced Sheet Pile Flood Wall.
This wall consists of a row of vertical pre-stressed concrete sheet piles, backed by batter piles connected to the sheet piles by a cast-in-place horizontal concrete beam with shear connectors as required to resist the vertical component of load in the batter pile . This type of wall has been used for coastal flood walls. It is ideal for wet areas because no excavation or dewatering is required to construct the wall. The disadvantage is that it is more indeterminate than other wall types. (Engineers, 1989)

2.6.7 Other Flood Barrier technologies.
The following is a review of patented technologies used in flood defense.

METHOD FOR THE FABRICATION OFA DAM OR BARRIER

A water dam includes a number of loading pallets arranged side-by-side and inclined outward from the water supported by supports. Membranes are placed on loading pallets and extend a distance in front of the pallets under the water. The membranes may be held down in the front edge by Stones, sandbags, etc. initially to hold the membrane in place. The supports are triangular and made of U-shaped sheet metal beams. The one on which the pallets rest grips over the adjoining legs of two loading pallets to hold these together. To the rear the support is extended Sufficient to secure that it cannot be tilted by the water. To achieve this and achieve a good grip on the ground the inclination is preferably 45, resulting in great vertical forces on the ground, a good grip on the ground. (Sten Kullberg, 2000)

CHAPTER THREE : METHODOLOGY.
Flood barrier proposed here in will be designed in the using the following methods;

3.1 Identification of flood prone areas.
To identify flood prone areas at the channel, information about previous flooding events and history will then be obtained using a combination of site visit and the ministry of Disaster Preparedness,Kampala City Council Authority,Other government publications. A flood risk analysis will be carried out following receipt of information collected above from which various parameters such as the extent or area of the flood plain, the average height of floodwaters.

3.2 Identification of technologies.
Resources used to study existing technologies included; Corporate publications,Government data,internet,research journal et cetera.

3.3 Design of the flood barrier.
The approach to flood barrier design chosen is one of the Federal Emergency Management Authority, FEMA (Agency, 2012).

3.3.1 Field Investigation for the proposed flood barrier.
Detailed information was obtained about the site and existing structures in order to make decisions and calculations concerning the design of the flood barrier. Key information that was collected included the low point elevation areas( that was mainly Bwaise),flood history , flood levels, environmental considerations and requirements by government, flood barrier regulations and community preferences.

Once the above data was collected and established,a conceptual design of the proposed flood barrier was made.

This discussion covered the following items:

- Previous floods and which areas where affected by floods.
- A plan of action as to which areas or structures can be protected by a flood wall and flood wall closures.
- Evidence of seepage/cracking in neighbouring structures’ foundation walls .
- A plan of action to use the flood wall to protect these structures from hydrostatic pressures from flood water.
- The various floodwall options and conceptual designs that would provide the necessary flood protection (obtain consensus on the favoured type, size, location, and features of the floodwalls).
- A plan of action for the design activity.

3.3.2 Flood Barrier design.
General.

Retaining walls and flood walls accommodate a difference in soil or water elevation over a typically short horizontal distance. On one side of the wall, the driving side, lateral forces exceed those on the opposite; resisting side; the force difference and resulting moment are accommodated by forces and pressures developed along the base. Lateral forces may be related to gravity, water seepage, waves, wind, and earthquakes. (Engineers, 1989).

The design of floodwalls consists of the proper selection and sizing of the actual floodwall and the specification of appurtenances such as drainage systems; waterproof materials to stop seepage and leakage; and miscellaneous details to meet site and homeowner preferences for patios, steps, wall facings, and support of other overhead structures (posts and columns). The following sections describe both a detailed design and a simplified design approach.

Limit-Equilibrium Analysis.
The forces and pressures acting on a wall are in fact highly indeterminate. Static equilibrium equations are insufficient to obtain a solution for lateral forces. Additional assumptions must be incorporated in the analysis. For nonlinear materials such as soils, this is commonly and conveniently done by assuming that a "limit" or failure state exists along some surface and that the shear force along the surface corresponds to the shear strength of the material. With these assumptions, equilibrium equations can be solved. Hence, this approach is commonly called "limit-equilibrium analysis." To assure that the assumed failure does not in fact occur, a factor (safety factor or strength mobilization factor) is applied to the material strength. It should be noted that this solution approach differs significantly from that commonly used for indeterminate structural analysis, where stress-strain properties and deformations are employed. This limit-equilibrium approach provides no direct information regarding deformations; it is implied that deformations are sufficient to induce to induce the failure condition. Deformations are indirectly limited to tolerable values by judicious choice of a safety factor, the failure condition. Deformations are indirectly limited to tolerable values by judicious choice of a safety factor.

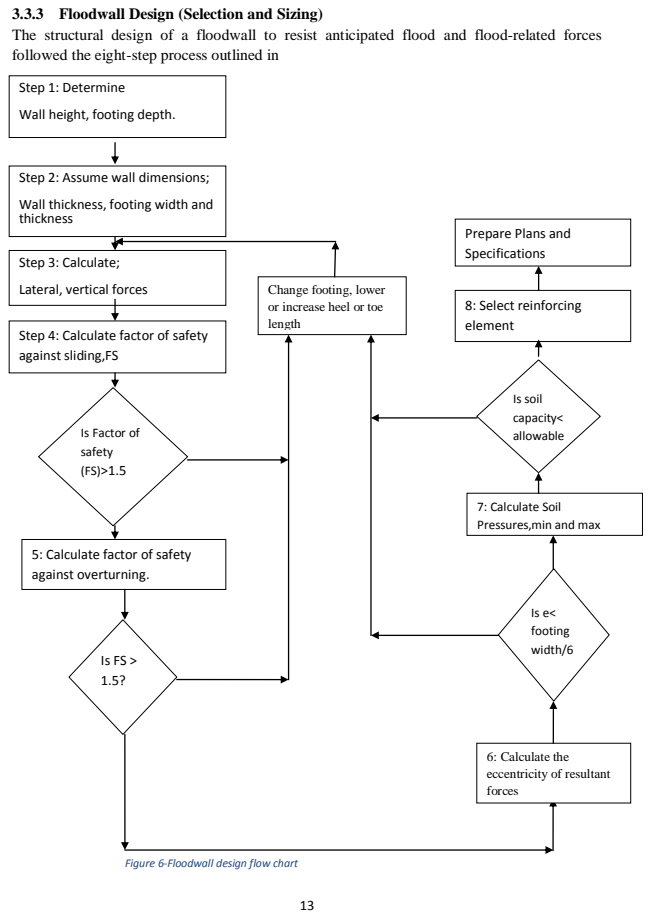
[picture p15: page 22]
Is e< footing width/6; Is soil capacity< allowable; 8: Select reinforcing element

3.3.3 Floodwall Design (Selection and Sizing)
The structural design of a floodwall to resist anticipated flood and flood-related forces
followed the eight-step process outlined in

Step 1: Determine
Wall height, footing depth.

Step 2: Assume wall dimensions;
Wall thickness, footing width and
thickness

Prepare Plans and
Specifications

Step 3: Calculate;
Lateral, vertical forces

Change footing, lower
or increase heel or toe
length

Step 4: Calculate factor of safety
against sliding,FS

Is Factor of
safety

7: Calculate Soil
Pressures,min and max

5: Calculate factor of safety
against overturning.

6: Calculate the
eccentricity of resultant
forces

Figure 6-Floodwall design flow chart

### 3.3 Floodwall joints and seal design

The floodwall joints chosen were anchor bolts of the heavy expansion type and the corresponding information about how they were to be designed for was obtained from both (Chan) and (UCAN Fastening Products, 2016).

Since the procedure of bolt selection was iterative, computer programs were built in Julia to carry out the calculations and any necessary iteration.

The output of the program was the bolt selection and its parameters were written passed to the python computer program.

Seals were designed using (FSA, 2017) and (Flexitallic). The process of seal selection was not iterative but however the process of selecting the seal bolts was iterative. As of such, a computer program was built in Julia to select both the seals and the bolts necessary.

3.4 Floodwall span and supports.
The floodwall supports and span were designed using a combination of simple bending theory from (Hearn, 2000) and Roark’s stress and strain Formulae (Young, 1989).

The span design was not an iterative process however it involved interpolation and multiple computations which would have raised the possibility of error if calculated by a human.

For another separate cause, since the author sought to simulate or test for multiple flood heights, it was in his best interests to automate the calculations in for these parts too.

Therefore a separate computer program was built in Julia to perform these procedures and thereby pass the resulting parameters or dimensioning to the CAD python program.

3.5 Structural analysis and Testing.
The python program was used to process the dimensioning from the Julia program upon which it built step files ( An industry export format for CAD).

These files were then read by CATIA upon which finite element analysis was done.

The test case upon which the testing was done was a flood of height 3ft, the value of the height was deliberately chosen to be higher than that obtained by the research done by (Dr. Richard Sliuzus, 2013) and (Habonimana, 2014) which was between 0.6m and 0.8m in inhabited areas along the flood plain of lubigi catchment.

3.6 Computer Code and data.
All computer code that was used in the design was modularized, though the main program (barrier1.jl) has dependencies with the modules used in the design of other components of the barrier.To use the code, the author had the Julia interpreter installed as well as the necessary dependencies ( the CSV Julia library and the Dataframes Library). The python program has a depency of FreeCAD that had to also be installed.The arrangement of the folders and computer code is as shown at https://github.com/TAUFEEQ1/floodwall-

Chapter 4: Design of the barrier
4.1.0 Flood Risk Assessment
The author chose to utilize the research done by Dr Richard Sliuzus et al on-Flood Risk Assessment, Strategies and Actions for Improving Flood Risk Management in Kampala (Dr. Richard Sliuzus, 2013).

The research paper details the simulation of flood scenarios and subsequent confirmations of the results obtained in two scenarios.

Scenario 0-baseline: the current baseline situation without improvement of the primary drain and a housing and road network pattern of 2010, derived from a high-resolution satellite image (0.5 m resolution). The channels are assumed to be not improved, relatively narrow and shallow, with partially blocking culverts (Dr. Richard Sliuzus, 2013).

Scenario 1-primary: the 2010 housing situation with improved primary drainage, execution of the current plan on the primary, cleaned secondary channels, wide culverts. The dimensions of the primary channel were taken as far as possible from the KDMP updated plan for Lubigi (ACE engineering, 2010). The model is tuned so that the simulated peak discharges are similar to the design discharges of this report (with channel flow resistance values and channel bed slope angle). This scenario was run a second time with non-cleaned secondary channels and partly blocked culverts, to illustrate that effect (Dr. Richard Sliuzus, 2013).

Scenario 0: baseline current situation The baseline situation (fig 3.2) shows severe flooding in many areas along the primary channel. Basically all areas west of Gayaza road are flooded on both sides of the primary channel, and a narrow area along the channel east of Gayaza road. Also North along the Gayaza road there is flooding, where secondary drains connect, but this area is not densely inhabited and poses less of a problem. The main problem areas are Bwaise III and Makerere III

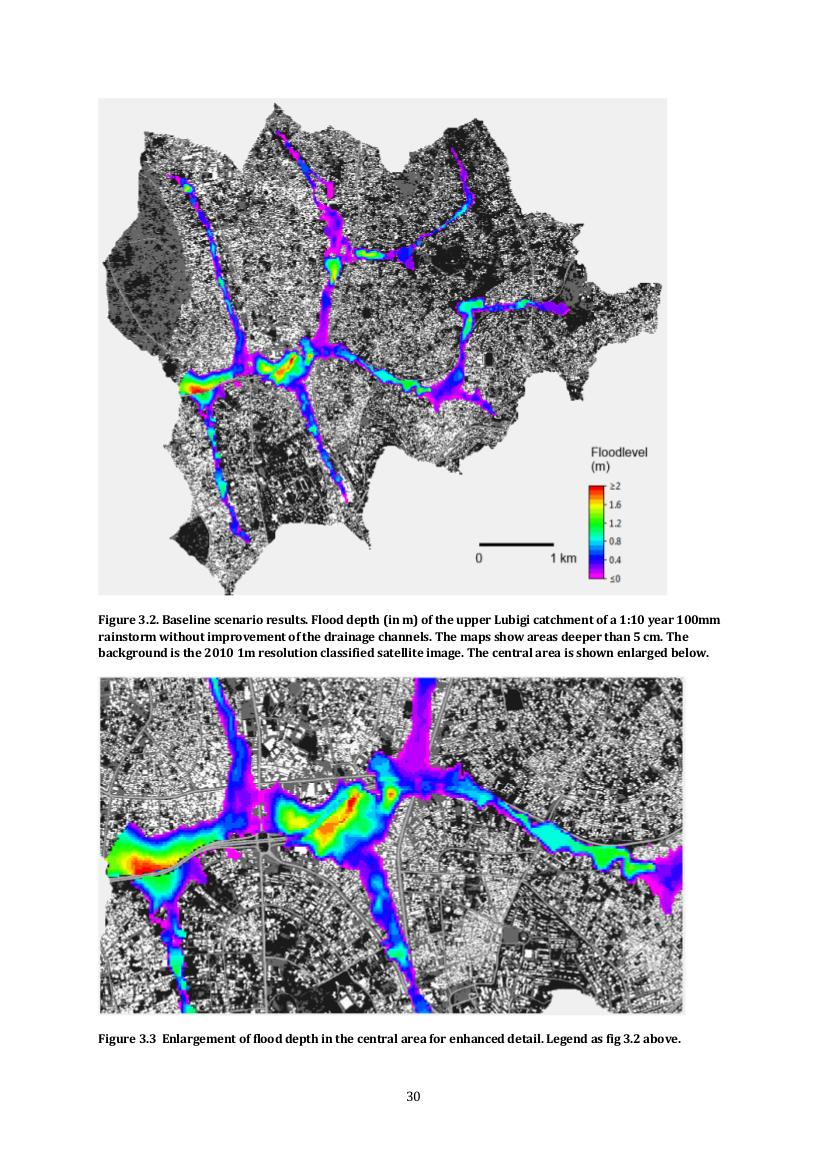
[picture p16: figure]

The most affected areas stay inundated for more than 12 hours. These are the southern half of Bwaise III, and the northern part of Kalerwe (Makerere III), as well as the area in between along the primary drain (fig 3.3). The deepest parts of the valley remain inundated for more than 20 hours (fig 3.4). Along the secondary drains the terrain is steeper and the flood duration is 4 to 5 hours. This is mainly caused by the terrain: the central valley is simply very flat and flow velocities are very low, while infiltration into the heavy clay soil is very slow. Most of the flood water has receded in less than 16 hours, bu

Scenario 1: Improved baseline conditions (primary improved, secondary cleaned) Improvement of the primary drainage system with its intended dimensions and large culverts, results in fewer flooded areas, certainly along the primary drain (see fig 3.5). The only really deep flooded area is south of the Northern Bypass, and a flatter area in the North East of the catchment where two secondary drains flow together. These areas are relatively uninhabited and cause fewer problems. All areas around the secondary drains remain flooded, but to a lower water depth in general because the water is evacuated from the catchment faster. The two hotspots in the unmitigated situation, Bwaise III and Kalerwe are less flooded.

Nevertheless, flooding still remains as the amount of water arriving from upstream is still large and this will not be drained rapidly because of the flat terrain. Improvement of culverts in the secondary channels has a clearly an effect, but this also delivers water more rapidly because of the flat ground.

In conclusion since scenario 0 has more floods with heights all the way to just over 2m the chosen design heights will use heights between 1m to just over 3m as the base line flood heights.

4.2.0 Floodwall Design
The design of floodwalls consists of the proper selection and sizing of the actual floodwall and the specification of appurtenances such as drainage systems; waterproof materials to stop seepage and leakage. A flood wall is a retaining wall and as of such, design considerations across the globe are very much more similar than different. As per the proposal, the author chose the guidelines set by the Federal Emergency Management Agency in the FEMA P-259 (Agency, 2012).

The following sections describe both a detailed design and a simplified design approach as derived from the above source.

### 4.2.1 Floodwall Selection and Sizing

The structural design of a floodwall to resist anticipated flood and flood-related forces follows the eight-step process outlined in the project proposalInvalid source specified.. The stability of the floodwall was investigated for different modes of failure which included the following;

Sliding: A wall, including its footing, may fail by sliding if the sum of the lateral forces acting upon it is greater than the total forces resisting the displacement. The resisting forces should always be greater than the sliding forces by a factor of safety of 1.5 (Agency, 2012).

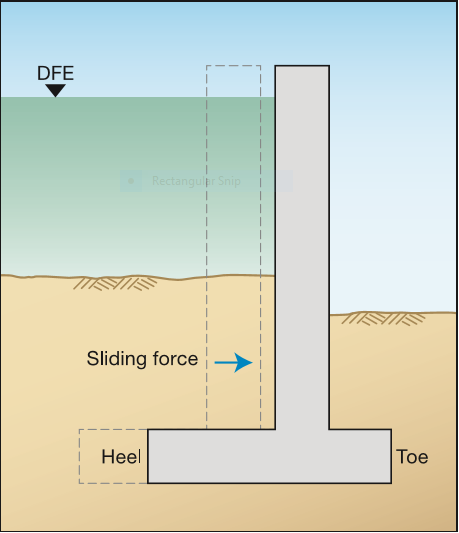
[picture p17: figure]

Figure 7-Illustration of wall failure by sliding

Overturning: Another mode of failure is overturning about the foundation toe. This type of failure may occur if the sum of the overturning moments is greater than the sum of the resisting moments about the toe. The sum of resisting moments should be greater than the sum of the overturning moments by a factor of safety of 1.5 (Agency, 2012).

Figure 8-Illustration of wall failure by overturning

Excessive Soil Pressure: Finally, a wall may fail if the pressure under its footing exceeds the allowable soil bearing capacity as will be discussed in the following sections.

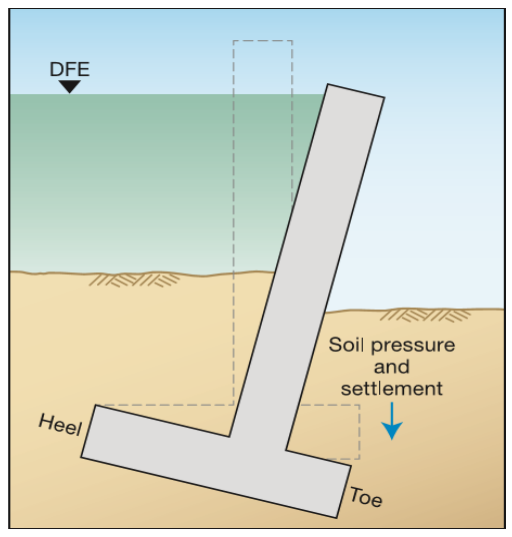
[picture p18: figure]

Figure 9-Illustration of settlement from excess soil pressure

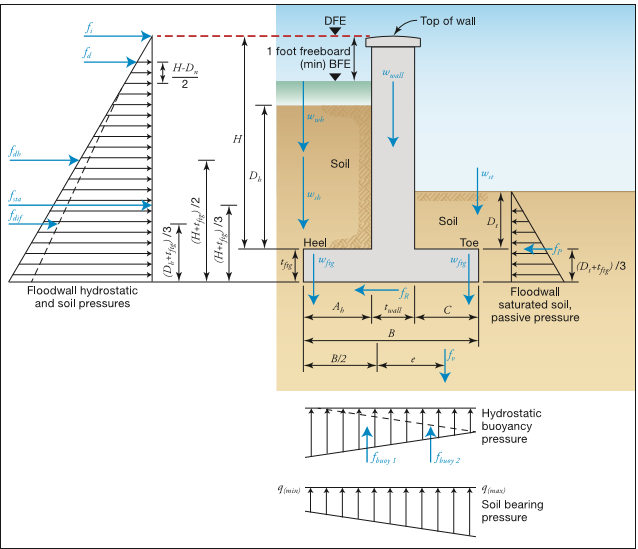
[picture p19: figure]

Figure 10-Force Diagram of generic floodwall design

Step 1: Determining wall height and footing depth.
- Determining wall height based on the DFE or BFE plus 1 foot of freeboard, whichever is greater was done using the studies (Habonimana, 2014) and (Dr. Richard Sliuzus, 2013) which showed that the heights were between 0.6m and 0.8m.
- Determine minimum footing depth based on the frost depth, local code requirements, and the soil conditions. The footing was to rest on suitable natural soil or on controlled and engineered backfill material.
- Given that in Uganda we experience no frost conditions, and that the proposed structure is demountable, the author thought it best the minimum footing depth be set to zero.
Step 2: Assume dimensions.
- Based on the following guidelines or reference to engineering handbooks, dimensions for the wall thickness, footing width, and footing thickness were assumed.

- The choice of wall thickness depends on the wall material, the strength of the material, and the height of the wall. Typical wall thicknesses are 8, 12, and 16 inches for masonry, concrete, or masonry/ concrete walls. Wall thickness in this particular project was dependent on the design flood elevation and those design decisions were to be made by the design engineer.
- The footing width depends on the magnitude of the lateral forces, allowable soil bearing capacity, dead load, and the wall height. The typical footing width is the proposed wall height. Typically, the footing is located under the wall in such a manner that 1/3 of its width forms the toe and 2/3 of the width forms the heel. This was used by the author.
Step 3: Calculate Forces.

There are two types of forces acting on the wall and its footing: lateral and vertical.

Lateral forces: These forces are mainly the hydrostatic and differential soil/water forces on the heel side of the wall, and the saturated soil force on the toe side of the wall. Hydrostatic and soil forces.

- Hydrostatic forces: The basic equation for analyzing the lateral force due to hydrostatic pressure from standing water above the surface of the ground is illustrated in Equation 1.

fst =

1
4

PH =

1
4
ɣH² | Equation 1.

Where

Fst = Lateral hydrostatic force in Ib/1ft.

H = flood proofing design depth.

P = hydrostatic pressure due to standing water at a depth of H (lb/ft² ), (P = ɣH).

ɣ = specific weight of water (62.4 lb/ft³

for fresh water and 64.0 lb/ft³ for saltwater).

Owing to the nature of the proposed structure, the force experienced was multiplied by the span length so as to establish the force experienced by the support in Ib.

Fst = fst ∗ len

Where Fst is the new lateral hydrostatic force and len is the span length.

The span length was to be determined by considering the span resistance to bending to be done separately.

Note: The structure proposed only experiences one lateral force that is the lateral hydrostatic force since the author proposed that there be no soil depth over the foot.

Vertical forces: The vertical forces are buoyancy and the various weights of the wall, footing, soil, and water acting upward and downward on the floodwall. The buoyancy force, fbuoy, acting at the bottom of the footing is computed as follows:

fbuoy = fbuoy 1 + fbuoy 2

with fbuoy1 and fbuoy2 computed as follows:

fbuoy 2 = baselengt 𝑕 ∗ ɣ C +

1
2

twall tfg

fbuoy 1 = γ ∗ H*(0.5twall)+((Ah+(0.5twall)(tfg))

where:

fbuoy = total force due to buoyancy (lb)

fbuoy1 = buoyancy force due to hydrostatic pressure at the floodwall heel acting at an approximate distance of B/3 from the heel (lb)

fbuoy2 = buoyancy force due to hydrostatic pressure at the floodwall toe, acting at an approximate distance of B/3 from the toe (lb)

w = specific weight of water (62.4 lb/ft3 for fresh water and 64.0 lb/ft3 for saltwater)

Ah = width of the footing above the heel (ft) C = width of the footing above the toe (ft)

H = floodproofing design depth(ft)

tfg = thickness of the floodwall footing (ft)

twall = thickness of the floodwall (ft)

The gravity forces acting downward are:

The unit weight of floodwall (wwall).

Wwall = H twall Sg ∗ wallwidt 𝑕

where:

Wwall = weight of the wall (lb)

H = floodproofing design depth (ft)

twall = wall thickness (ft)

Sg = unit weight of wall material S (lb/ft3)

The unit weight of the footing (wftg)

Wfg = baselengt 𝑕 ∗ Btfg Sfg

where:

wfg = weight of the footing (lb)

B = width of the footing (ft)

tfg = footing thickness (ft)

Sfg = unit weight of wall material (concrete is 150 lb/ft3)

and the unit weight of the water above the heel (wwh):-

ws𝑕 = baselengt 𝑕 ∗ A𝑕

H ɣ

where:

wwh = weight of the water above the heel (lb)

Ah = width of the footing heel (ft)

H = floodproofing design depth (ft)

ɣ = specific weight of water (62.4 lb/ft3 for fresh water and 64.0 lb/ft3 for saltwater).

The total gravity forces acting downward, wG, in pounds per linear foot can be computed as the sum of the individual gravity forces computed above.

wG = wwall + wfg + ww𝑕

wG = total gravity forces acting downward (lb)

wwall = weight of wall (lb)

wftg = weight of footing (lb)

wwh = weight of water above the heel (lb).

fv = wG − fbuoy ≥ 0

Where;

fv = net vertical force (lb)

wG = total gravity forces acting downward (lb)

fbuoy = total force due to buoyancy (lb)

The net vertical forces in Equation 5F-14 must be greater than or equal to zero. If the value is determined to be less than zero, the designer should change the footing dimensions, then go back to Step 3 and try again.

Step 4: Calculate factor of safety against sliding.

This step involves the computation of the sliding forces, the forces resisting sliding, and the factor of safety against sliding. For a stable condition, the sum of forces resisting sliding should be larger than the sum of the sliding forces.

1) Sliding Forces: The sum of the sliding (lateral hydrostatic, hydrodynamic, and impact) forces, fcomb, is computed as follows:

fcomb = fst + fd𝑕 + fi

Fi and Fdh are assumed to be zero as the water flows parallel to the barrier.

Fst is the hydrostatic force and acts at (H + tfg)/3

Resisting Forces: The forces resistant to sliding are the frictional force, ffr, between the bottom of the footing; the cohesion force, fc, between the footing and the soil; and the soil and the saturated soil force, fp, over the toe of the footing. These resisting forces are computed as follows:

Frictional Force: The frictional force, ffr, between the bottom of the footing and the soil is a function of net vertical force, fv, times coefficient of friction, Cf. The coefficient of friction, Cf, between the base and the soil depends on the soil properties.

ffr = Cffv

Where;

ffr = friction force between the footing and the soil (lb)

Cf = coefficient of friction between the footing and the soil

fv = net vertical force acting on the footing

Cohesion Force: The cohesion force between the base and the soil, fc, is obtained by multiplying the width of the footing, B, by the allowable cohesion value of the soil. This allowable cohesion value is usually obtained from a geotechnical analysis of the soil. The cohesion between the footing and the soil may be destroyed or considerably reduced due to contact from water. Due to potentially high variations in the allowable cohesion value of a soil, the cohesion is usually neglected in the calculations; unless the value of cohesion is ascertained by soil tests or other means, it should be taken as zero in the calculations.

fc = baselengt 𝑕 ∗ CsB

where:

fc = cohesion force between the base and the soil (lb)

Cs = allowable cohesion force between (lb/ft2) (usually assumed to be zero) B = width of the footing (ft)

Force due to passive soil pressure at heel:

fp =

baselengt 𝑕 ∗ 1
2

kp

ɣsoil − ɣwater

+ ɣwater

∗ tfg

2

where: fp = passive saturated soil force (lb)

ɣsoil = unit weight of the soil (lb/ft3)

tfg = thickness of the floodwall footing (ft)

kp = passive soil pressure coefficient

ɣwater = specific weight of water (62.4 lb/ft3 for fresh water and 64.0 lb/ft3 for saltwater).

tkey= thickness of key

Force due to passive pressure from wall span:

fwallsp =

spanlengt 𝑕 ∗ 1
4

kp

ɣsoil − ɣwater

+ ɣwater

tbase

2

Passive soil force from key:

fkey =

baselengt 𝑕 ∗ 1
2

kp

γsoil − γwater

+ γwater

tbase

2

The sum of the resisting forces to sliding, fR, is calculated as the sum of the individual resisting forces to sliding,

fR = ffr + fc + fp + fwallsp + fkey

where:

fR = resisting force to sliding (lb)

ffr = friction force between the footing and the soil (lb)

fc = cohesion force between the base and the soil (lb)

fp = passive saturated soil force over the toe (lb)

fwallsp = passive saturated soil force from wall span under soil.

Factor of Safety Against Sliding: For the stability of the wall, the sum of resisting forces to sliding, fR, should be larger than the sum of the sliding forces, fcomb. The ratio of fR over fcomb is called the Factor of Safety against sliding, FS(SL), and is calculated as:

FS =

fR

fcomb + fi

≥ 1.5

where:

FS = factor of safety against sliding (should be greater than 1.5)

fR = sum of the forces resisting sliding in (lb)

fcomb = sum of the sliding forces (cumulative lateral hydrostatic force) (lb) fi = normal impact force (lb)

for the purposes of these project fi is assumed to be zero or negligible as the water flow is parallel to the barrier.

The factor of safety against sliding in Equation 5F-14 should be at least 1.5. If the factor of safety is determined to be less than 1.5, the designer should lower the footing, increase the amount of fill over the footing, and/or change the footing dimensions, then go back to Step 3 and try again.

Step 5: Calculate factor of safety against overturning. The potential for overturning should be checked about the bottom of the toe (Figure 5F-5). For a stable condition, the sum of resisting moments, MR, should be larger than the sum of the overturning moments, MO. The ratio of MR over MO is called the Factor of Safety against overturning, FS(OT).

Overturning Moments: The overturning moments are due to hydrostatic and hydrodynamic forces, impact loads, saturated soil, and the buoyancy forces acting on the footing. The sum of the overturning moments, MO, is calculated as:

Force from key= bas elengt 𝑕 ∗1
2

kp

ɣsoil − ɣwater

+ ɣwater

∗ tkey

2

MO = fst

H + tfg
3

+ fbuoy 1

2B
3

+ fbuoy2

B
3

+ fkey

2
3

tkey

where:

MO = sum of the overturning moments (ft-lbs).

fst = lateral hydrostatic force due to standing water (lb).

fbouy1 = buoyancy force, in lb, due to hydrostatic pressure at the floodwall heel acting at an approximate distance of B/3 from the heel.

fbouy2 = buoyancy force, in lb, due to hydrostatic pressure at the floodwall toe, acting at an approximate distance of B/3 from the toe.

B = width of the footing (ft)

H = height of the wall (ft)

tfg = thickness of the floodwall footing (ft)

Resisting Moments: The resisting moments are due to all vertical downward forces and the lateral force due to soil over the toe. The sum of resisting moments, MR, is calculated as:

MR = Wwall C +

twall
2

+ Wfg

B
2

+ Ww𝑕 B −

A𝑕
2

+ fp

tfg
3

+ fwallsp

tfg
3

where:

MR = sum of the resisting moments in (ft-lbs).

Wwall = weight of the wall (lb).

twall = wall thickness (ft).

tfg = footing thickness (ft).

wftg = weight of the footing (lb/lf)

B = width of the footing (ft)

C = width of the footing toe (ft)

Ah = width of the footing heel (ft)

wwh = weight of the water above the heel (lb)

fp = passive saturated soil force over the (lb)

Factor of Safety Against Overturning: As mentioned earlier, for a stable condition, the sum of resisting moments, MR, should be larger than the sum of the overturning moments, MO, resulting in a factor of safety greater than 1.0. However, the factor of safety against overturning, FS(OT), computed in Equation 5F-17 should not be less than 1.5. If FS(OT) is found to be less than 1.5, the designer should increase the footing dimensions, then go back to Step 3 and try again.

FSOT =

MR
MO

≥ 1.5

Step 6: Calculate eccentricity.

The final resultant of all the forces acting on the wall and its footing is a force acting at a distance, e, from the centerline of the footing. This distance, e, is known as eccentricity. The calculation of eccentricity is important to ensure that the bottom of the footing is not in tension. The eccentricity value is also needed for the calculation of soil pressures in Step 7. The eccentricity, e, is calculated as:

e =

B
2

−

MR − MO
fv

where:

e = eccentricity (ft)

B = width of the footing (ft)

fv = net vertical force acting on the footing (lb)

MO = overturning moment (ft-lbs)

MR = resisting moment (ft-lbs)

This eccentricity, e, should be less than 1/6 of the footing width. If e is found to exceed B/6, change the footing dimensions, go back to Step 3, and try again.

Step 7: Calculate soil pressures. The soil pressures, q, are determined from the following equation.

q =

fv

B ∗ baselengt 𝑕

1 ±

6e
B

where:

q = soil pressure created by the forces acting on the wall (lb/ft2)

fv = net vertical force acting on the footing (lb) (Eq. 5F-8) B = width of the footing (ft) e = eccentricity (ft)

The maximum value of q should not exceed the allowable soil bearing capacity. The bearing capacity of soil varies with the type of soil, moisture content, temperature, and other soil properties. The allowable values should be determined by a geotechnical engineer. Some conservative allowable bearing values for a few soil types are given in Table 5F-1. If the computed value of q is more than the allowable soil bearing value, increase the footing size, then go back to Step 3 and try again.

4.3.0 Design of anchor bolt and base plate
Anchor bolts have been extensively used over the world for connecting steel structures to concrete structures. They can be either cast-in or post-installed. However, in many cases, the concrete has already been cast and set and therefore the anchor bolts are normally post-installed.

In European countries, the European Organisation of Technical Assessment (EOTA) published the Guideline for European Technical Approval of Metal Anchors for Use in Concrete (Approvals, 2010). Anchor bolts which acquire European Technical Assessments or formerly known as European Technical Approvals (ETAs) must fulfill the requirements given in (Approvals, 2010). On the other hand, the European Committee for Standardization (CEN) published Design of Fastenings for Use in Concrete (CEN/TS 1992-4) [2] which provides technical specifications on anchor bolt design which is based on the limit state approach.

The author in the case of the project chose to refer to the guidelines provided by Guide on Design of post-installed anchor bolt systems in Hong Kong by Chan specifically in as they relate to design of mechanical anchor bolt joints as opposed to chemical anchors.

It should be noted the procedure that is the (failure mechanisms, static analysis et cetera) is largely similar with that suggested by EOTA in (Approvals, 2010) except in numerical values and requirements.

4.3.1 Design procedure of mechanical anchor bolts
The design procedure of a single anchor bolt or an anchor bolt group is presented as follows.
1. Determine the design forces of the anchor bolt / bolt group. Identify design requirements, e.g. seismic, crack / non-cracked concrete, strength of concrete, corrosion and fatigue, etc.
2. Select an anchor based on design requirements. Determine the preliminary anchor bolt size, the anchor bolt layout, the dimensions of the base plate, the spacing and edge distances, etc.

3. Resolve the design forces into tension and shear of individual anchor bolt according to Section 3.2 (Chan) and 3.3 (Chan).
4. Calculate the design tension resistances of the anchor bolt according to Section 4.2 (Chan).
5. Calculate the design shear resistances of the anchor bolt according to Section 4.3 (Chan).
6. Compare the design anchor bolt forces to the design resistances according to Sections 4.1 (Chan) and 4.4 (Chan).
7. If the design resistances are larger than the design anchor bolts force, OK! If not, repeat the procedure from Step 2.
Step 1:

To determine the design forces of the anchor bolt / bolt group. Identify design requirements, e.g. seismic, crack / non-cracked concrete, strength of concrete, corrosion and fatigue, etc.

In the case of the proposed structure, the author shall as a conservative approach assume the concrete is cracked as supported by (Chan) and (Approvals, 2010) in absence of other guidance provisions.

The value of the strength of concrete, corrosion and fatigue will depend on the site conditions upon which the flood barrier base/footing is to be installed chosen in the first procedure.

Step 2:

To select an anchor based on design requirements.

The author chose to use mechanical anchor bolts as opposed to chemical anchor bolts because the structure proposed is demountable and temporary.

It can also be said that the curing time is a major disadvantage of chemical anchor bolts, whereas mechanical anchor bolts can be installed relatively immediately the same cannot be said about mechanical anchor bolts.

Determine the preliminary anchor bolt size, the anchor bolt layout, the dimensions of the base plate, the spacing and edge distances, etc.

Spacing and edge distances as well will be determined from the design of the floodwall base above and manufacturer’s manual which in this case was the UCAN manual (UCAN Fastening Products, 2016).

Step 3:

Resolve the design forces into tension and shear of individual anchor bolt according to Section 3.2 (Chan) and 3.3 (Chan).

The design forces facing the anchor bolts in the proposed structure are mainly from the lateral hydrostatic force and moment.

Lateral hydrostatic force can be obtained from Equation 1 and the overturning moment can be determined from Equation 2.

The lateral force results in shear force on the anchor bolts whereas the overturning moment results in a vertical tensile load on some anchor bolts as well as a compression on the others.

R1 =

Mo
s

R1 = the tensile force faced by the two bolts,

Fst = Lateral hydrostatic force.

H = floodproofing height.

Mo = Overturning moment.

And since R1=-R2, R2 is compressive on the remaining two bolts.

Individual tensile force by the bolts = R1/2

Shear force = lateral hydrostatic force.

Step 4:

Calculate the design tension resistances of the anchor bolt according to Section 4.2 (Chan)

The characteristic value of bolt resistance, to tension of an anchor bolt can be calculated directly by;

NRKS = As ∗ fuk

Where;

As is the cross-sectional area of the bolt.

Fuk is the ultimate tensile stress of the bolt.

And As can be determined from the preliminary selection.

Design for pull-out resistance: Unfortunately, this can only be obtained from experiments or lab tests (Approvals, 2010).

Design for concrete cone resistance:

The characteristic cone resistance in ideal conditions can be got from the formula;

NR

°
kc

= kc fc𝑕ef

1.5

Where;

Kc=factor specified by the manufacturer and dependent on the condition of the concrete

fc= concrete characteristic cube strength in N/mm²

𝑕ef= embedment depth of the anchor in mm.

Design for splitting resistance:

Splitting failure due to installation can be avoided if the minimum requirements of edge distance , spacing smin and the concrete thickness 𝑕min are met. Engineers shall refer to the manufacturer design manual for the minimum requirements of edge distance, bolt spacing smin and concrete thickness hmin

Step 5:

Calculate the design shear resistances of the anchor bolt according to Section 4.3.

Design against steel failure by shear:

The characteristic shear resistance can be calculated directly by:

VRKS = 0.5AS ∗ fuk

Where;

As is the bolt cross-sectional area

fuk is the ultimate shear stress.

Design against concrete edge failure:

VRKC = k1 ∗ dnom

α ∗ l f

β
∗ fcu ∗ c1

1.5

Where

dnom is the outside diameter of the anchor bolt ≤ 60 mm

lf is the effective length of the anchor bolt = hef ≤8.0dnom

c1 is the edge distance in the direction of the shear force.

Design against concrete pry out failure:

The characteristic value of concrete pry-out resistance can be calculated in a similar manner as:

VRkcp = k3 ∗ NRKC

Where;

k3 = pry-out factor given in the relevant approval documents.

NR KC = characteristic value of concrete cone failure resistance calculated for anchor bolts resisting shear forces.

By engineering experience, k3 =1. 0 for post-installed anchor with h<60mm and k3=2. 0 for post-installed anchor with 𝑕≥60mm (Approvals, 2010) and (Chan). Alternatively, the design value of concrete pry-out resistance, can be found in manufacturer design manual.

Resistance to combined tension and shear forces:

The combined effect of tension and shear will be calculated as follows:

Nsd

NRd

2
+

Vsd

VRd

2
≤ 1.0

The above equation is to be used when the mode of failure is steel failure otherwise use the one below:

Nsd

NRd

1.5
+

Vsd

VRd

1.5
≤ 1.0
Step 7:

If the design resistances are larger than the design anchor bolts force, OK! If not, repeat the procedure from Step 2.

Design resistance are estimated using partial factors of safety

ɣMC covers concrete break-out failure modes (i.e. cone failure, edge failure and pry-out failure).

ɣMS covers steel failure by tension and shear.

ɣMS = 1.2

fuk

fyk

≥ 1.4…… for tension;

ɣMS = 1.0

fuk

fyk

for fuk

fyk

≤ 0.8…. for shear; and the value of this factor is greater than or equal to

1.25

ɣMS = 1.5 for fuk

fyk

> 0.8

ɣMC = ɣcɣ2

where

ɣcpartial factor for concrete under compression = 1.5

ɣ2partial factor taking into account the installation safety of the fastening system

As of the scope of this project ɣ2 will be set to 1.00 for high installation safety in tension and ɣ2
is set to 1.0 for all scenarios.

The author has chosen to use bolt data obtained from tables provided by UCAN. As of this writing, UCAN Fastening Products is a wholly Canadian owned company specialized in concrete anchoring systems.

Bolts type chosen were heavy load expansion anchors (carbon steel) and tension data used is included in Table 2B-SZ (UCAN Fastening Products, 2016).

Shear design data chosen was from Table 3A-SZ (UCAN Fastening Products, 2016).

### 4.4.0 Design of the Floodwall span:

For the design of the span, the author chose to use method proposed in the FEMA guidelines for floodwall closures and appurtenances.

Whatever material is used(in this case alpha alumina corundum was used properties obtained from www.matweb.com), it must be of sufficient strength and thickness to resist bending and deflection failures. The ability of a specific material to withstand bending stresses may be substantially different from its ability to withstand deflection stresses. Therefore, to provide for an adequate factor of safety, the required closure thickness should be calculated twice: first taking into account bending stresses, and second taking into account deflection stresses. The resulting thicknesses should be compared and the larger value specified in the final wall span design.

One method of determining the thickness of the closure for steel and aluminum is presented in Roark’s formulas for stress and strain (Young, 1989). For a flat plate supported on three sides, the plate thickness required due to bending stresses may be determined by the following equation:

t =

P𝑕 ∗ Wc

2 ∗ β
Maxσ

Where

t = plate thickness (in.)

Ph = hydrostatic pressure due to standing water (psi).

Wc = width of closure (in.)

Max σ = allowable stress for the plate material (from material handbooks) (lb/in.2)

β = moment coefficient from Table 15 from (Agency, 2012).

Similarly, for a steel or aluminum flat plate supported on three sides, the plate thickness required due to deflection stresses may be determined by the following Equation:

t =

360 ∗ α ∗ P ∗ Wc

3
E

Where;

α = deflection coefficient from Table 15 from (Agency, 2012).

E = modulus of elasticity for the plate material (from material handbooks) (lb/in.2)

Ph = hydrostatic pressure due to standing water (psi).

Allowable values for α and E may be found for steel plates in the Steel Construction Manual (AISC, 2005), and for aluminum plates in the Aluminum Construction Manual (AA, 1959).

4.5.0 Design of the supports of the wall span/plate
The design of the support was done following simple bending theory detailed in the book Mechanics of Materials 1 by EJ Hearn (Hearn, 2000).
Step 1:

Establish bending moment on the cantilever support:

Accordingly, the bending moment of a uniformly varying load of the nature in which the load decreases uniformly towards the free end as in the case being discussed is given by the formula,

M =

w ∗ l

2
6

Where

W = load per unit height

L = height of the barrier.

W is also given by:

w =

2 ∗ fsta
barrier_𝑕eig𝑕t

Where fsta is the hydrostatic force given earlier.

Step 2:

Establish material elastic limit or yield stress

Step 3:

Determine section modulus:

Z =

M
yield _stress
Step 4:

Choose any I section that meets the required value above, using trial and error.

The I section must be able to house the wall span and have an allowance for the seals/gaskets.

Step 5:

Update the values of the wall thickness and repeat the entire procedure of the structure design (floodwall foundation et cetera).

4.7.0 Design of the gaskets:
A gasket/seal is to be placed between wall span and the support, and between the support and foundation.

The author used methods and considerations in the (FSA, 2017) and (Flexitallic).

Operating Conditions

Condition one requires a minimum load be determined in accordance with the following equation:

Wm1 =

3.14G

2P
4

+ 2b3.14GmP

This equation states the minimum required bolt load for operating conditions and is the sum of the hydrostatic end force, plus a residual gasket load on the contact area of the gasket times a factor times internal pressure. Stated another way, this equation requires the minimum bolt load be such that it will maintain a residual unit compressive load on the gasket area that is greater than internal pressure when the total load is reduced by the hydrostatic end force.

In the case of this structure, there exists no hydrostatic end force,

Wm1 = 2b3.14GmP

Since the seal is of rectangular section the formula becomes,

Wm1 = 2 ∗ b ∗ j ∗ m ∗ P

Where

b is the gasket width

j is the length

m is the maintenance factor.

P is the internal pressure which in this case is the hydrostatic pressure.

Gasket Seating: (condition two)

Requires a minimum bolt load be determined to seat the gasket regardless of internal pressure and utilises a formula:

Wm2 = 3.14bGy

The “b” in these formulae is defined as the effective gasket width and “y” is defined as the minimum seating stress in psi.

Modifying formula for rectangular section, where j is the length of the seal.

Wm2 = b ∗ j ∗ y

b = bo when bo ≤ 1/4”… b = 0.5 √bo when bo> 1/14”

After Wm1, and Wm2 are determined, the minimum required bolt area Am is determined as follows:

Am1 =

Wm 1
Sb

where Sb is the allowable bolt stress at operating temperature, and

Am2 =

Wm 1
Sa

where Sa is the allowable bolt stress at atmospheric temperature

Then Am is equal to the greater of Am1 or Am2. Bolts are then selected so the actual bolt area, Ab, is equal to or greater than Am.

Since there is a risk of chemical attack as the pH of the water is variable, the designer saw it fit that Sigma products were chosen to be used as they have outstanding chemical resistance suitable across the whole pH range (0-14).

4.7.1 Design of seal bolts:
Fasteners are also made of aluminum (the most commonly used alloys being 2024-T4, 2111-T3, and 6061-T6), brass, copper, nickel, Monel, Inconel, stainless steel, titanium, beryllium, and various plastics. For any application the fastener material must be considered in connection with potential corrosion problems associated with the anticipated environment and the other metals involved (Section 9.2 of (Robert C.)). In addition, appropriate coatings should be considered for corrosion protection and to reduce thread friction and wear.In this case the designer chose to use alpha alumina corundum alloy.

For most applications, screws and nut-bolt assemblies should ideally be tightened to produce an initial tensile force Fi nearly equal to the full “proof load,” which is defined as the maximum tensile force that does not produce a normally measurable permanent set. (This is a little less than the tensile force producing a 0.2 percent offset elongation associated with standard tests to determine Sy.) On this basis initial tensions are commonly specified in accordance with the equation:

Fi = Ki ∗ At ∗ Sp

Where:

Fi = Initial tensile force;

Ki = a constant in ordinary static loading cases is 0.9 (Robert C.)

At = tensile area of the thread Tables10.1 and 10.2 of (Robert C.)

Sp = Proof stress in Tables 10.4and 10.5 (Robert C.)

From Table 14(Robert C.) Proof strength for SAE Class 4.6 is 225MPa for diameters 5mm to 36mm.

The official American National Standard from which the information in Table 10.1 (Robert C.) was taken is ANSI (American National Standards Institute) B1.1 (1974), which is published by the American Society of Mechanical Engineers and sponsored jointly by the ASME and the Society of Automotive Engineer

For the design of these bolts, it is assumed that their performance at operating temperature and atmospheric temperature doesn’t vary. As of such Wm1 and Wm2 will be compared in magnitude and the greater of the two will be chosen or selected.

4.8.0 Site Drainage:
The drainage system for the area enclosed by a floodwall or levee must accommodate the precipitation runoff from this interior area (and any contributing areas such as roofs and higher ground parcels) and the anticipated seepage through or under the floodwall or levee during flooding conditions. There are two general methods for removing interior drainage. The first is a gravity flow system, which provides a means for interior drainage of the protected area when there is no floodwater against the floodwall or levee. This is accomplished by placing a pipe(s) through the floodwall or levee with a flap gate attachment. The flap gate prevents flow from entering the interior area through the drainpipe when floodwater rises above the elevation of the pipe. The second method, a pump system, removes accumulation of water when the elevation of the floodwater exceeds the elevation of the gravity drain system. A collection system composed of pervious trenches, underground tiles, or sloped surface areas transports the accumulating water to a sump area. In the levee application, these drains should be incorporated into the collection system. The anticipated seepage from under and through floodwalls and levees must also be taken into consideration by combining it with flow from precipitation (see Figure 4-14) (Agency, 2012). It is important to verify that the pump system has a reliable power source that can handle the flooding in the area enclosed by the floodwall or levee. This is essential to the performance of the floodwall or levee system. To determine the amount of precipitation that can collect in the contained area, the rainfall intensity, given in inches per hour, must be determined for a particular location. This value is multiplied by the enclosed area, Ad, in square feet, a residential terrain runoff coefficient (c) of 0.7, and a conversion factor of 0.01. The answer is given in gallons per minute (gpm). See

RUNOFF QUANTITY IN AN ENCLOSED AREA

The rational equation is used to compute the amount of precipitation runoff from small areas. It is generally not applicable to drainage areas greater than 10 acres in size.

Q = 0.01 ∗ c ∗ ir ∗ Ad

Where:

Q = run off of the enclosed area

0.01 = factor for converting answer to gpm

C = residential terrain run off coefficient of 0.7

Ir = Intensity of rainfall (inch/hr)

Ad = Area Enclosed by the floodwall

Seepage flow rates from the levee or floodwall, Qc, must also be estimated. In general, unless the seepage rate is calculated by a qualified soils engineer, a value of 2 gpm for every 300 feet of levee or 1 gpm for every 300 feet of floodwall should be assumed during base 100-year-flood conditions.

The estimated flow rate from seepage is given by:

Q = sr ∗ l

Sr is the seepage rate per foot of barrier

L is the length of the barrier wall

If the floodwall is in such a way that it partially encloses a protected area and that there exists high ground that is draining into the protected area, the flow rate or drainage rate for that too must be established.

Q = 0.01 ∗ c ∗ ir ∗ Ab

Where c,ir are as decribed in the above equation and Ab is the area of the high ground.

The minimum discharge for pump installation is therefore:

Qmin = Q𝑕ig𝑕_ground + Qseepage + Qprotected _area

4.8.1 Design of sump pump applications.
The design of sump pump applications follows the procedure outlined in the flow chart

Figure 11-Sump pump design procedure

Step 1:
From the previous section, Drainage rates were obtained.
Step 2:
Determine the location for sump. This entails establishing wether there are subfloor considerations that would interefere with pump installations. It also entails finding out wether submerged pump is tolerable or acceptable.
Step 3:
Determine location for discharge.
It is not permissible to discharge into sanitary systems as this may raise health risks and risks of operational failure as a result of blockage.
Therefore as a result of this consideration, the discharge will be made into the water body or channel.

Step 4:
Selecting pump size:
In selecting a pump, the designer needs the following information:
- Estimate of the quantity of floodwater that will infiltrate into the space per unit of time
- The total dynamic head for the sump discharge. This equals the vertical distance from the pump to the point of discharge plus the frictional resistance to flow through the piping, the fittings, and the transitions. Use the preliminary sketch and field investigation information developed earlier to determine these parameters.
- The head loss due to pipe friction can be obtained from hydraulic engineering data books and is dependent on the pipe material and pipe length.
TOTAL DISCHARGE HEAD

TDH = Z + 𝑕fpip e + 𝑕ffittings + 𝑕ftrans

Where;
TDH is the Total Discharge head in ft
Z is the elevation difference between the bottom of the sump and the point of discharge. Hfpipe is the head loss due to pipe friction.
Hffittings is the head loss through the fittings.
Hftrans is the head loss through the transitions.

Head losses due to pipe transitions and fittings.

𝑕ffittings + 𝑕ftrans = Kb + Kc + Ke

(

V

2
2g

)

Where:
hf-fittings = head loss through pipe fittings (ft)
hf-trans = head loss through the transitions (ft)
Kb = loss coefficient of the pipe fitting(s), taken from hydraulic engineering data books
Ke = loss coefficient of the pipe entrance, assumed to be 0.5
Ko = loss coefficient of the pipe exit/outlet, assumed to be 1.0 V = velocity of flow through the pipe , taken from hydraulic engineering data books (ft/sec) g = acceleration of gravity, 32.2 (ft/sec2)
Step 5: Select pump size.
The capacity and size of the sump depends on two factors: physical size of the sump pump; and recommendations of the sump pump manufacturer regarding pump cycling or other constraints. The designer should take these considerations into account in locating the sump and configuring the sump pump discharge.
Step 6:
- Select discharge piping route:

- measure minimize length of pipe between sump and discharge point;
- avoid utility and structural components along route;
- attach discharge pipe to structure as required by code; and
- protect discharge point against erosion.
Steps 6 to 8:

These steps are to be done according to specifications from Geotechnical and Electrical personnel and are beyond the scope of the project.

ASSEMBLY OF STRUCTURE:

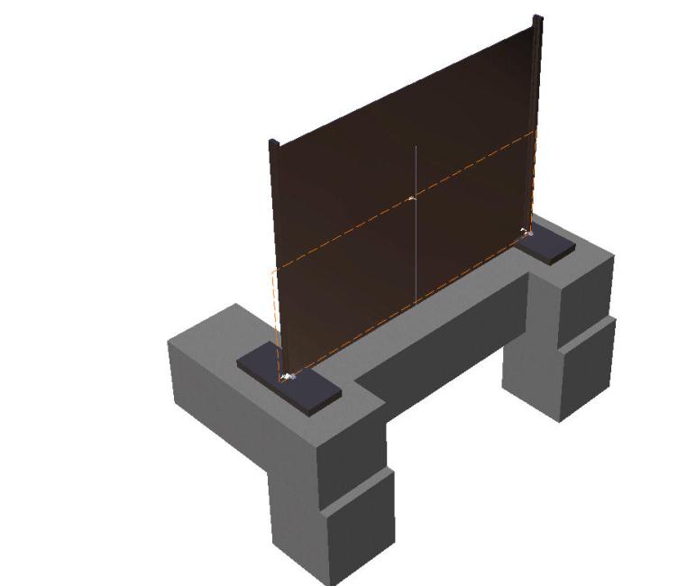
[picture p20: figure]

Figure 12-Assembly of structure

Figure 13-front of assembly

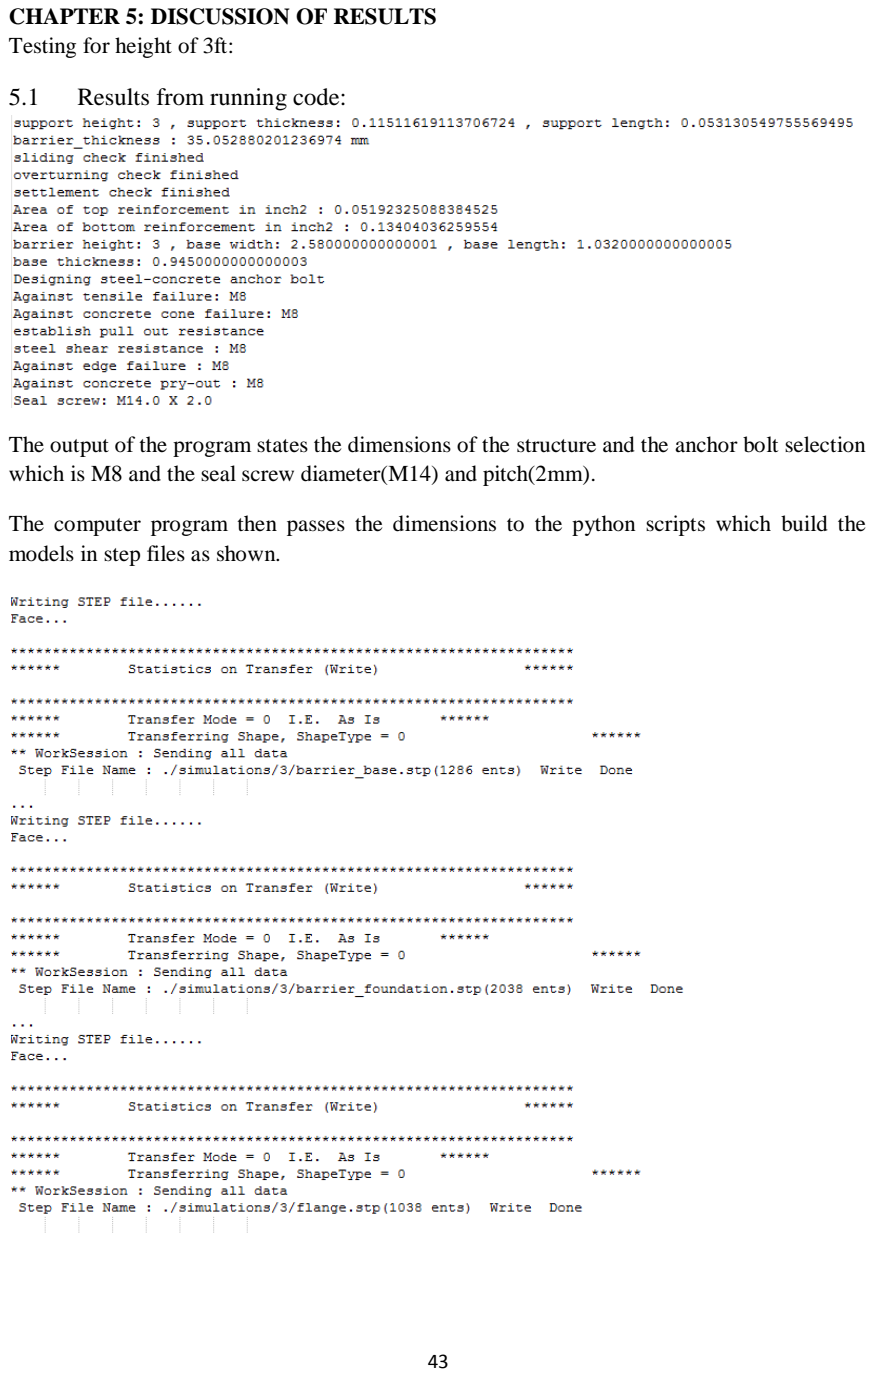
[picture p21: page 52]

CHAPTER 5: DISCUSSION OF RESULTS Testing for height of 3ft:

5.1 Results from running code:

The output of the program states the dimensions of the structure and the anchor bolt selection which is M8 and the seal screw diameter(M14) and pitch(2mm).

The computer program then passes the dimensions to the python scripts which build the models in step files as shown.

### 5.2 Loading on base / foundation statically

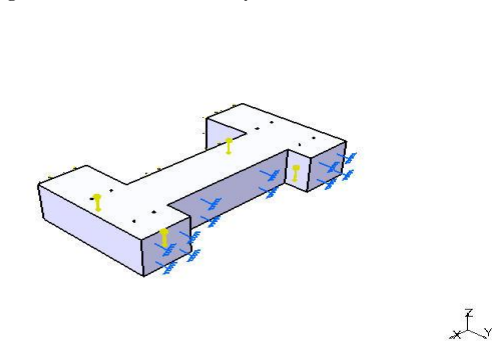
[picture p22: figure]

Figure 14-Loads on foundation

The foundation of the structure was loaded with its own weight, the horizontal load in the y-axis from the hydrostatic force, a couple from the overturning moment caused by the hydrostatic force.

The material properties are listed in Table-1:

Table 1-Material properties , base

Material | Concrete
Young's modulus | 2.5e+010N_m2
Poisson's ratio | 0.3
Density | 2320kg_m3
Coefficient of thermal expansion | 1e-005_Kdeg
Yield strength | 0N_m2

Applied loads sets are shown in Table-2:

Table 2-Applied load set for base

Components | Reactions | Residual | Relative Magnitude Error
Fx (N) | 0.00E+00 | -4.67E-09 | -4.67E-09
Fy (N) | 1.32E+03 | -1.32E+03 | -5.95E-09
Fz (N) | -5.03E+06 | 5.03E+06 | -2.79E-08
Mx (Nxm) | 2.59E+05 | -2.59E+05 | 5.94E-09
My (Nxm) | -1.53E-07 | 1.38E-07 | -1.43E-08
Mz (Nxm) | 5.45E-10 | -1.48E-08 | -1.42E-08

### 5.2.1 Deformed Mesh

Figure 15-Deformed Mesh

Figure 15 shows the resultant deformed mesh after applying the load set in Table 2.The resulting bending moments from the load set deform the foundation of the barrier in the shape shown in Figure 15. The deformation shown here does not affect the functioning of the barrier since it does not reduce its effective height which would result in a risk of operational failure.

### 5.2.2 Static case solution Von misses Stress

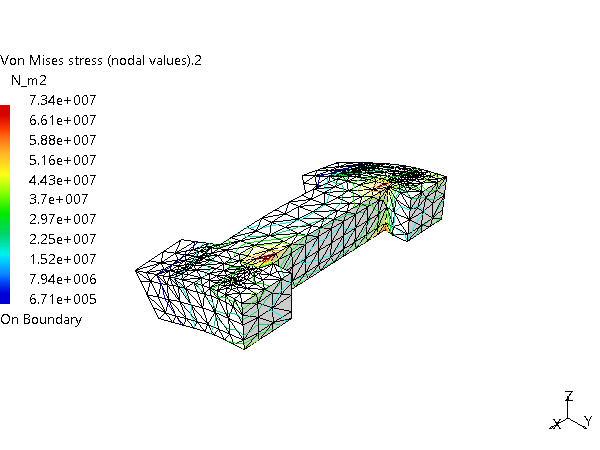
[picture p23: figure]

Figure 16-Von Mises Stress on foundation

Figure 16shows that the stress distribution on the foundation from the loads and moments on the base/foundation.

5.2.3 Translational displacement Vector

Figure 17-Translational displacement Vector of base

Figure 17 shows the translational displacement vector which shows the maximum displacement less than 3mm which still shows structural integrity. Since a displacement of this magnitude is not likely to affect the functioning of the structure and the concrete retains its elasticity, the result shows that flood barrier design is viable.

5.3 Static loading supports.

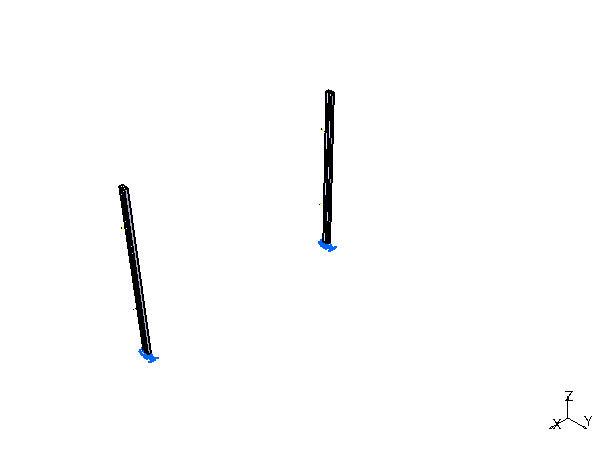
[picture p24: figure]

Figure 18-Loading supports statically

Figure 18 shows the metal frames that form the supports in the structure, their material properties are as shown in Table 3 , below:

Table 3-Material properties, supports

Material | Aluminium
Young's modulus | 7e+010N_m2
Poisson's ratio | 0.346
Density | 2710kg_m3
Coefficient of thermal expansion | 2.36e-005_Kdeg
Yield strength | 9.5e+007N_m2

Figure 18 also shows the loads, and restraints on the supports that are numerically described in Table-4 below:

Table 4-Applied loadset on supports

Components | Applied Forces | Reactions Residual | Relative Magnitude Error
Fx (N) | 9.18E-15 | 9.45E-09 | 9.45E-09
Fy (N) | 1.32E+03 | -1.32E+03 | -5.01E-08
Fz (N) | -2.39E-14 | -1.71E-09 | -1.71E-09
Mx (Nxm) | -1.02E+03 | 1.02E+03 | 5.34E-08
My (Nxm) | -1.36E-13 | 9.78E-09 | 9.78E-09
Mz (Nxm) | -9.42E-07 | 9.31E-07 | -1.17E-08
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

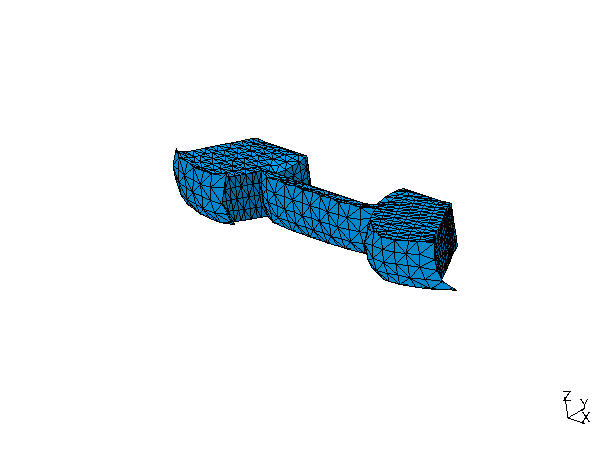
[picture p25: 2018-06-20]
barrier/file4_5ab4cf1a.jpg

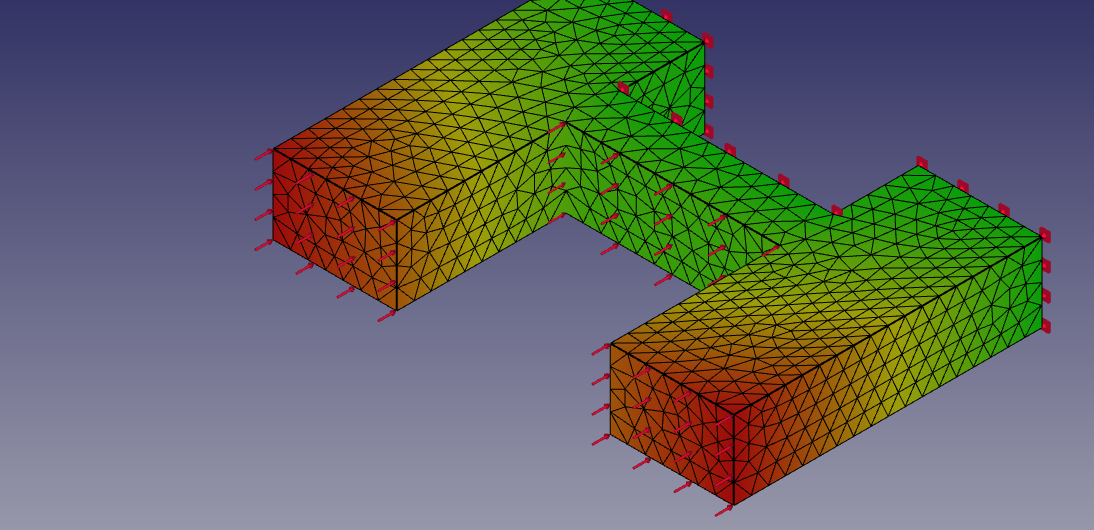
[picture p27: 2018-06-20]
barrier/hulio.bmp

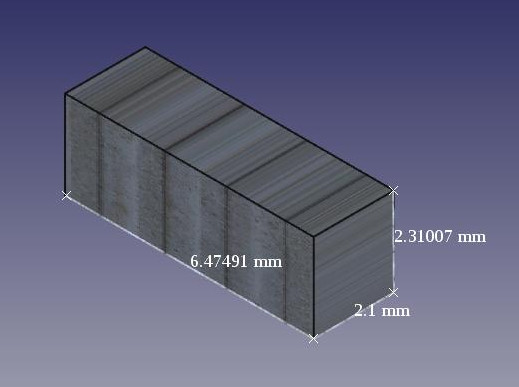
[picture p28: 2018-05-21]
barrier/barrier_base.jpeg

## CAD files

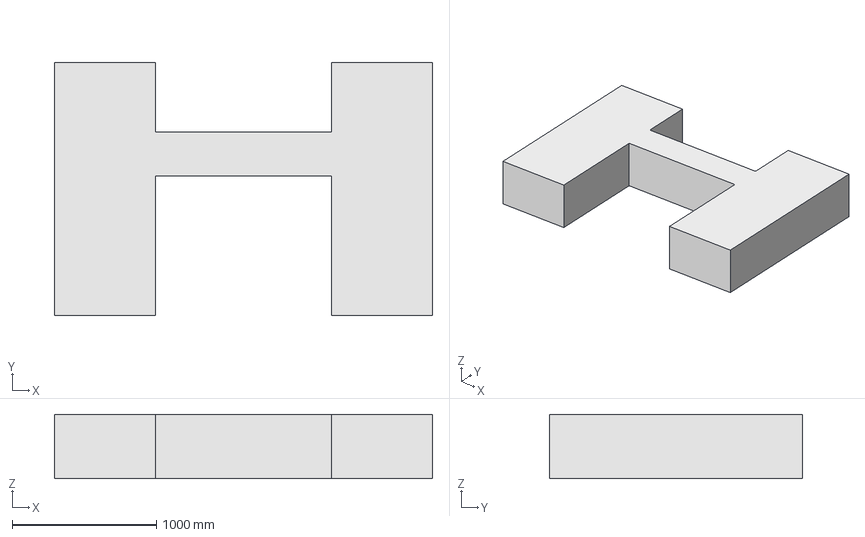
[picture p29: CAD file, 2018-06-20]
barrier/compression.FCStd
2618.7 x 1750.9 x 445.3 mm

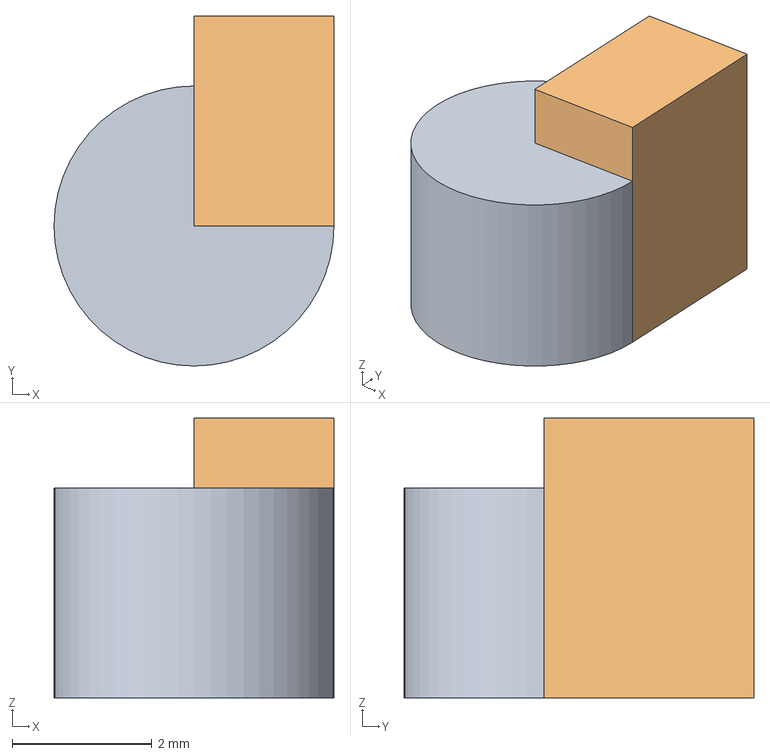
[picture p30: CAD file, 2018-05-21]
btry.stp
4.00 x 5.00 x 4.00 mm

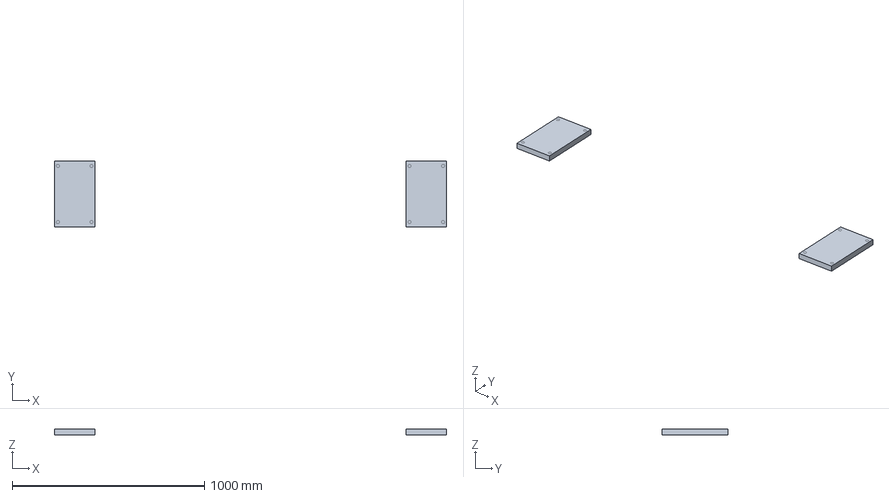
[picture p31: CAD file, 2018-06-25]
simulations/3/flange.stp
2037.0 x 343.7 x 30.0 mm

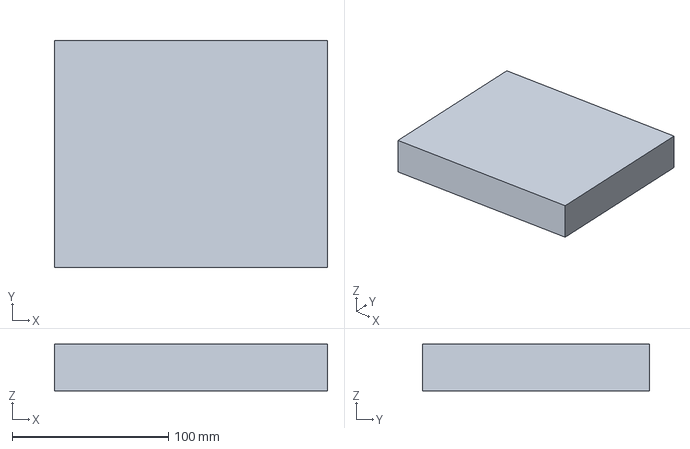
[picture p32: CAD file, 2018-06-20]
barrier/flange_plate.stp
175.0 x 145.8 x 30.0 mm

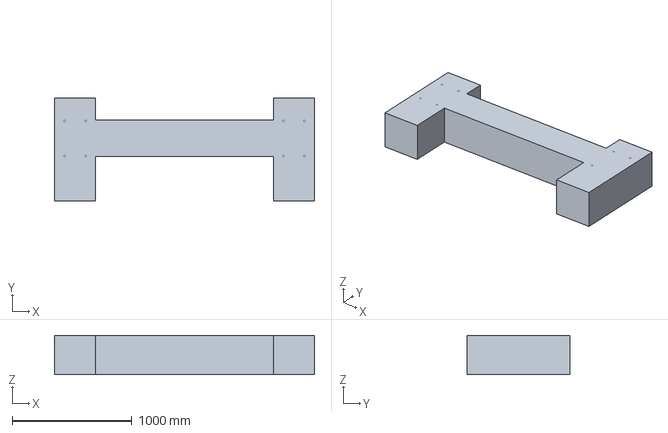
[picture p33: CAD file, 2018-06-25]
simulations/3/barrier_base.stp
2170.5 x 858.7 x 328.9 mm

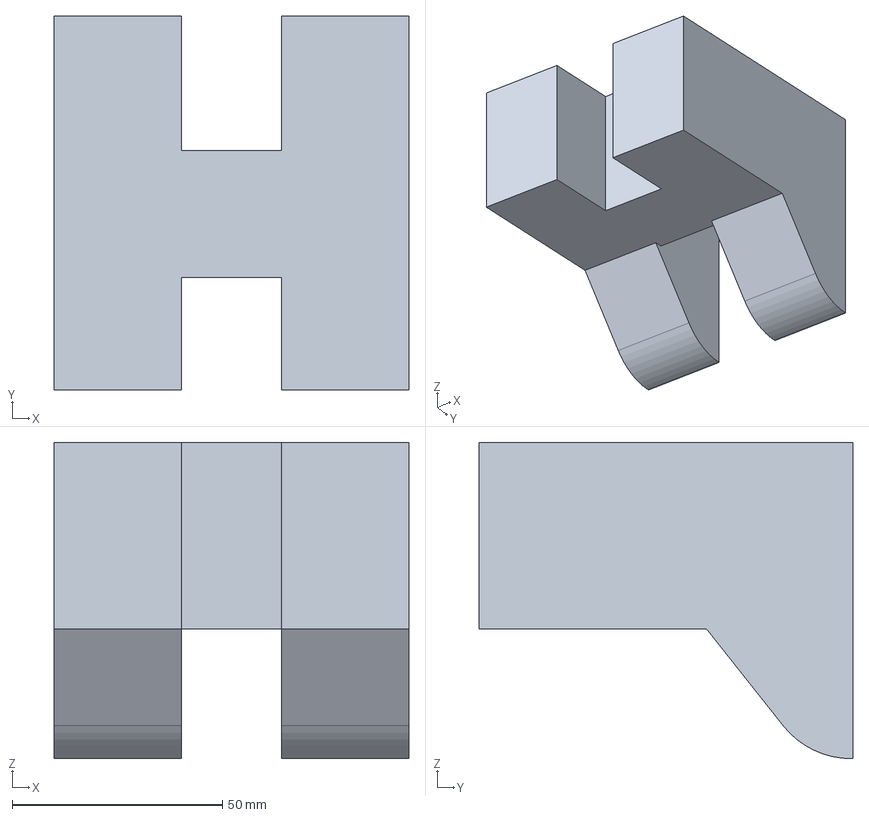
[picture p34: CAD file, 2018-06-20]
barrier/Part1.stp
84.5 x 88.9 x 75.2 mm

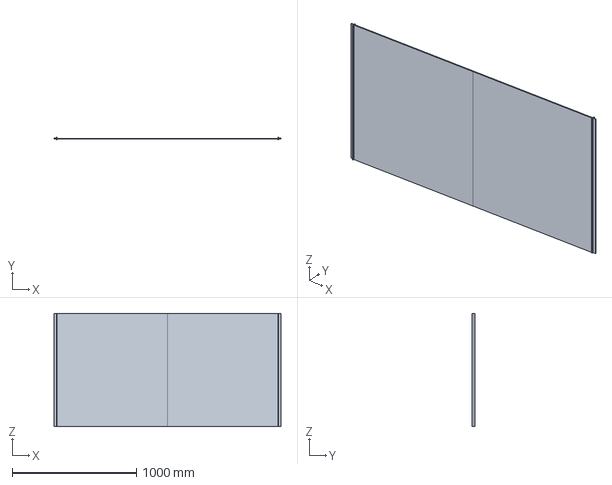
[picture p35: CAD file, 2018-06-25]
simulations/3/wall_span.stp
1827.0 x 22.7 x 913.5 mm

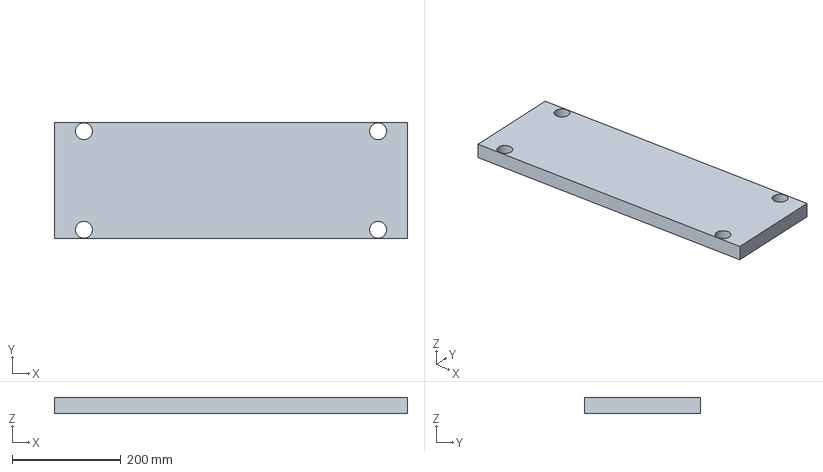
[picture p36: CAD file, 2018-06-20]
barrier/flange.stp
648.0 x 213.0 x 30.0 mm

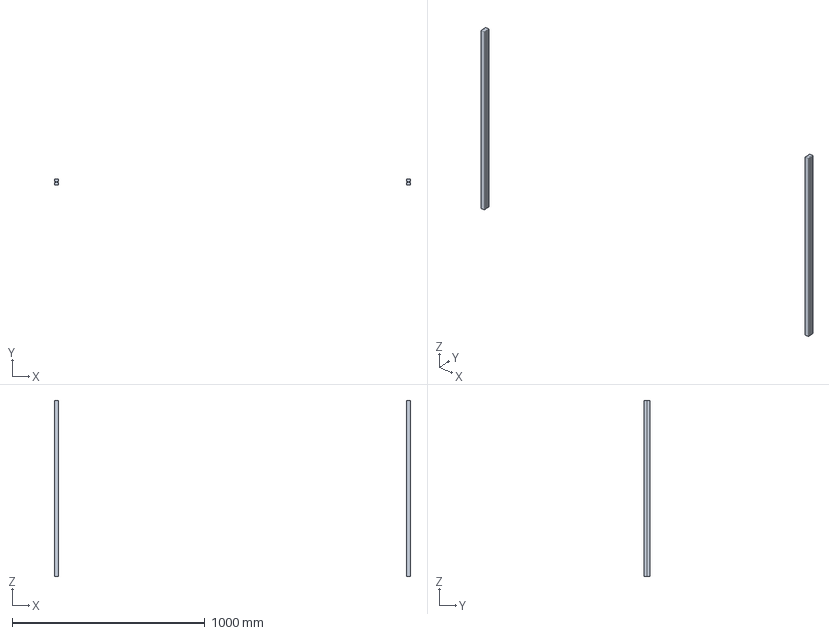
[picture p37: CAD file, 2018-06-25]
simulations/3/frames.stp
1846.5 x 32.4 x 913.5 mm

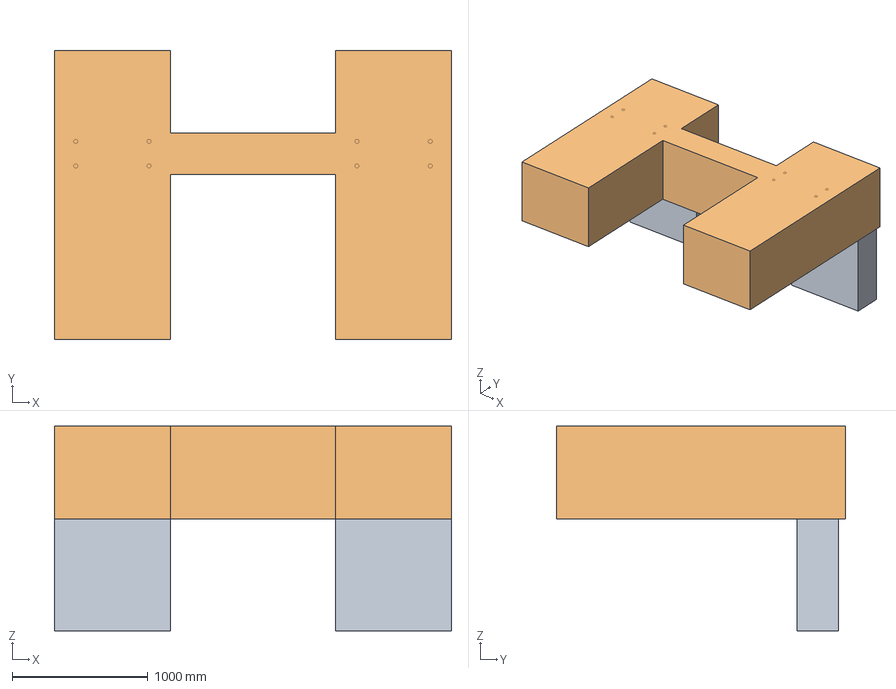
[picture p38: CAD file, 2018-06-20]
barrier/barrier_foundation.stp
2923.2 x 2131.5 x 1507.3 mm

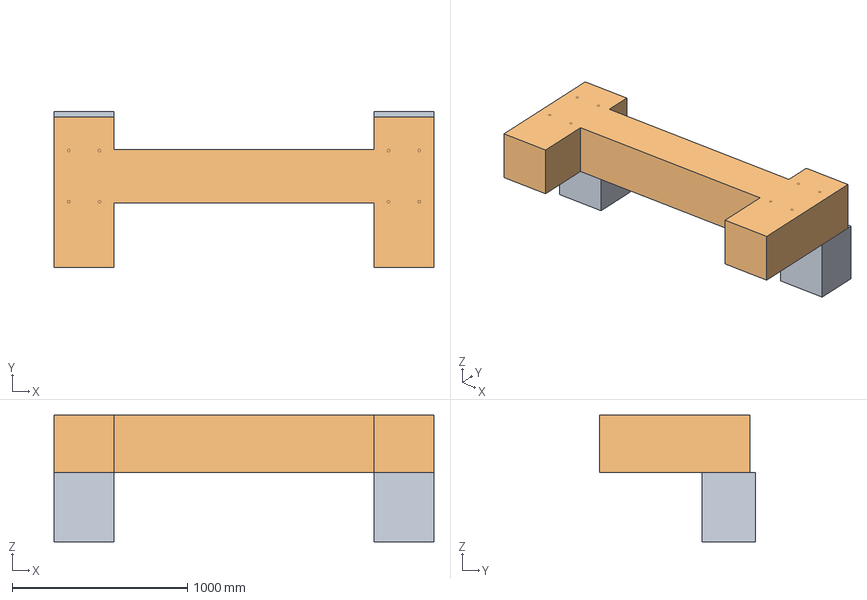
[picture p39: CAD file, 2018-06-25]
simulations/3/barrier_foundation.stp
2170.5 x 891.4 x 723.5 mm

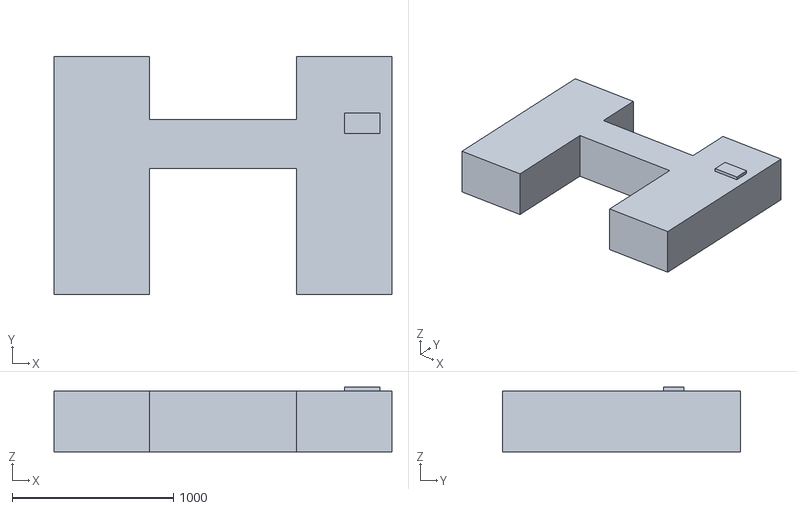
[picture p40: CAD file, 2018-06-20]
barrier/c.obj
2095.0 x 1476.8 x 401.8

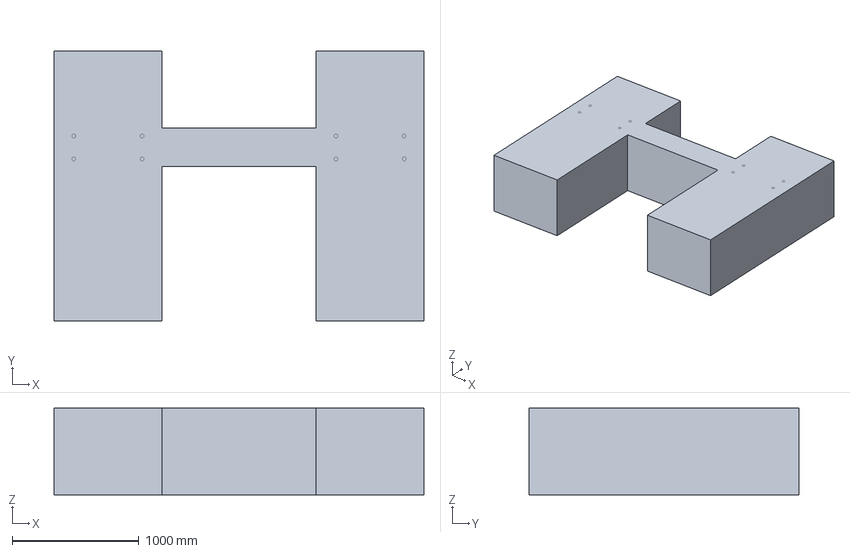
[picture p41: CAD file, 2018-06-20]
barrier/barrier_base.stp
2923.2 x 2131.5 x 685.1 mm

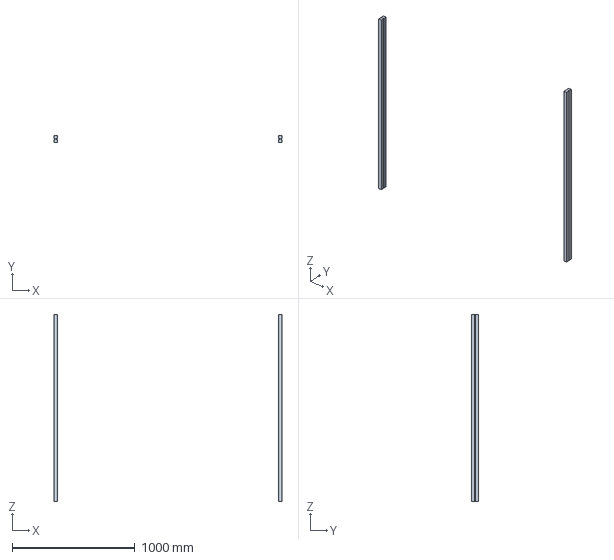
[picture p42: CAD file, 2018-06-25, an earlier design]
simulations/5/frames.stp
1854.1 x 58.7 x 1522.5 mm

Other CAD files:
simulations/5/barrier_foundation.stp
simulations/5/wall_span.stp
simulations/5/flange.stp
simulations/5/barrier_base.stp
barrier/barrier_base.fcstd

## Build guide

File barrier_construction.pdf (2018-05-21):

2/18/2018 | barrier.py
file:///tmp/tmpqafwev.html | 1/1

02/18/18 01:58:04 /home/nsamba/projects/barrier.py

1 | #!/usr/bin/freecadcmd
2 | import | | Part
3 | from | | FreeCAD | | import | | Base
4
5 | base_width | | = | | float(input("What was your base_width?"))
6 | base_length | | = | | float(input("What was the base_length?"))
7 | base_length | | = | | float(input("What was your base_length?"))
8 | base_thick | | = | | float(input("What was your base_thickness?"))
9
10 | def | | design_base(bwidth,blength,bheight):
11 | | pos | | = | | Base.Vector(0,0,0)
12 | | s | | = | | Part.makeBox(bwidth,blength,bthick,pos)
13 | | nsolid | | = | | Part.makeSolid(s)
14 | | p | | = | | Base.Vector()
15 | | drill | | = | | Part.makeCylinder()
16 | | nsolid.exportStep("/home/nsamba/projects/barrier/barrier_base.stp")
17
18 | def | | design_barrier(wwidth,wheight):
19 | | pos | | = | | Base.Vector(0,0,0)
20 | | # | to be finished
21
22 | design_base(base_width,base_length,base_thick)

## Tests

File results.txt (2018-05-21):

barrier height: 5 , base width: 3.500000000000001 , base length: 1.4000000000000004
base thickness: 1.5750000000000004
barrier height: 5 , base width: 5.200000000000003 , base length: 2.0800000000000014
base thickness: 1.5750000000000004
barrier height: 5 , base width: 6.200000000000003 , base length: 2.4800000000000013
base thickness: 1.5750000000000004
The bolt for resisting tension is: M10

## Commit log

2018-06-20 added changes to barrier project
    [barrier_base.stp, barrier_foundation.stp, flange.stp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]
2018-06-20 minor changes to folder structure
    [barrier.csv, hole_params.csv, lit.cfg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]
2018-06-25 new project
    [barrier_base.stp, barrier_foundation.stp, flange.stp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]
2018-06-25 For three ft
    [barrier_base.stp, barrier_foundation.stp, flange.stp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]
